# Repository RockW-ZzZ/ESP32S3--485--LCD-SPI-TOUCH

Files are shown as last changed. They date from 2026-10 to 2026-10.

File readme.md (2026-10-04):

# ESP32-S3 双路隔离 RS485 / SPI LCD / 触摸屏

本文是项目文档总入口。目标模组为 **ESP32-S3-WROOM-1U-N16R8**（16 MB Flash、
8 MB Octal PSRAM），固件使用本机 **ESP-IDF 6.1**，项目目录沿用 `fireware`。

## 当前功能与资源

| 功能 | 外设和 GPIO | 当前行为 |
| --- | --- | --- |
| LCD | ST7796S，SPI2；MOSI1 / SCLK5 / DC3 / CS4 / BL6 / RESET10 | 480×320 横屏，RGB565，上电运行 LVGL 8.4 benchmark |
| 触摸 | GT911；SCL7 / SDA8 / INT9，与 LCD 共用 RESET10 | 上电启用，坐标与横屏一致 |
| RS485 第一路 | UART1；TX17 / RX18 / DE21；CN1 3/4 针 | 独立充电器 1 控制，运行设定每 15 秒写入 |
| RS485 第二路 | UART2；TX11 / RX12 / DE14；CN1 1/2 针 | 独立充电器 2 控制，与第一路并行 |
| CN2 隔离逻辑串口 | UART0；TX43 / RX44 | 默认 115200、8N1 |
| KEY2 | GPIO40，低有效 | 长按 2 秒切换触摸，一次按住只切换一次 |
| KEY1 | GPIO41，低有效 | 保留备用，只读状态，按下/松开各 200 ms 稳定滤波 |
| 下载与日志 | USB Serial/JTAG；GPIO19 / GPIO20 | 不占用三个业务 UART |
| 有源蜂鸣器（新增硬件） | HNB09A03 + SS8050；GPIO13；R30 10 kΩ 基极下拉 | 高电平鸣叫、低电平停止；上电关闭，网页开关 |

两路 485 默认分别运行 demo 充电器协议，独立控制两台充电器。启动先请求关机，运行中
每 15 秒写入电压/电流；首次启动预装设定、开关机和保护停机立即执行。网页提供选路、
CC/CP、预设、爬坡、保护、统计、波形、配色、配网和 OTA。通用 Modbus `03/04/06/10`
驱动保留；关闭充电应用后可启用双路只读示例。详见 [充电控制说明](fireware/CHARGER.md)。

蜂鸣器在最新原理图中已改用 GPIO13，GPIO35～37 继续保留给内部 PSRAM。
器件参数、驱动方式及 R28 装配建议见 [硬件说明第 4.4 节](hardware/原理图说明.md)。

## 文档索引

| 文档或资料 | 维护内容 |
| --- | --- |
| [项目进度](项目进度.md) | 当前阶段、已实现功能、验证边界及后续工作；LCD 保留 LVGL benchmark，暂未移植旧屏幕 UI |
| [硬件原理图说明](hardware/原理图说明.md) | 电源与隔离边界、器件/接口、引脚、UART 分配、样机检查 |
| [原理图 PDF](hardware/PCB/SCH_Schematic1_2026-10-04.pdf) | 当前四页电路连接的原始依据 |
| [立创 EDA 工程](hardware/PCB/ProDoc_Board1_2026-10-04.epro2) | 原理图、器件属性与 BOM 装配标记的编辑源 |
| [LCD 引脚及尺寸图](hardware/LCD/3.5寸LCD尺寸和引脚.png) | 屏幕外形、接口位置 |
| [LCD 模组与芯片资料](hardware/LCD/中景园ZJY350S11CTG21电容触摸技术资料-ST7796) | ST7796、GT911、模块原理图和厂家示例；详细文件见硬件说明索引 |
| [固件使用与 API](fireware/README.md) | 编译/烧录、默认行为、驱动调用、配置与验证步骤 |
| [双路充电控制与网页](fireware/CHARGER.md) | 移植范围、网络入口、15 秒写入时序、厂家协议、API、OTA 与验收 |
| [固件依赖清单](fireware/DEPENDENCIES.md) | 项目内依赖、本机工具、独立构建及删除旧参考目录后的验证 |
| [LVGL 移植说明](fireware/components/lvgl/PORTING.md) | LVGL 版本、包含范围、板级适配、字体/图片与配置 |
| [mDNS 来源与校验](fireware/components/mdns/SOURCE_SHA256.json) | 官方 mDNS 1.10.0 固定提交与文件 SHA-256 |
| [mDNS 许可](fireware/components/mdns/LICENSE) | 已内置 mDNS 的 Apache-2.0 许可 |
| [LVGL 原始许可](fireware/components/lvgl/LICENCE.txt) | 第三方源码的 MIT 许可 |
| [LVGL 文件校验表](fireware/components/lvgl/SOURCE_SHA256.json) | 398 个原始文件的 SHA-256 |
| [固件测试](fireware/tests) | 协议、触摸坐标、双路通信、按键/防误触策略及独立性校验脚本 |

## 构建和使用

在 PowerShell 中：

```powershell
Set-Location fireware
.\build.ps1 build
.\build.ps1 menuconfig
# COM5 为示例，替换为实际 USB Serial/JTAG 端口。
.\build.ps1 -IdfArgs @('-p', 'COM5', 'flash', 'monitor')
```

使用已有 SDK 和工具链，不升级；LVGL、mDNS 和网页资源已内置，构建无需联网下载它们。全部编译所需项目文件已放入 `fireware`，
`ref-code` 可由用户删除；本文及构建均不将它作为必需资料目录。硬件资料保留在 `hardware`。
`demo`、`tmp` 中的现有内容不是正式固件的构建输入。

LVGL benchmark 完成后在屏幕和 USB 日志显示结果。GPIO40 只控制触摸输入，关闭触摸不
停止 LCD 刷新或 benchmark。重新打开时，仍按住屏幕的手指需先松开；状态不保存，重启恢复开启。
GPIO41 没有业务动作。实体充电 UI 与 EC11 暂不移植，后续改用 LVGL 触摸 UI。

默认热点 `ChargerCtrl` / `12345678`；访问 `http://192.168.4.1/` 自动跳转到 8899 端口，
默认 PIN `1234`。STA 配网后可通过局域网 IP 或 `charger.local` 访问。
本次新增双 OTA 应用槽，首次从旧固件升级需通过 USB 完整烧录分区表和应用。

## 文档维护规则

1. 电路、位号或接口改变时，同步更新硬件说明、原理图导出文件及该说明中的 SHA-256。
2. GPIO/UART/按键行为改变时，同时更新固件 `board_pins.h`、驱动/配置、固件 README 与本页资源表。
3. 新增第三方源码或资源时，文件与许可放入 `fireware`，更新依赖清单和相应版本/校验记录。
4. 新增正式文档时，在本页索引登记，使用相对链接；不要链接计划删除的旧参考目录。
5. 验证记录区分编译、主机模拟测试与实板测试，不用编译通过代替实机通信或 FPS 结果。

2026-10-05：本轮验证记录见 [充电控制说明](fireware/CHARGER.md#验证与实板验收)。
测试包含原有 19 组驱动测试、新增 14 组充电控制测试和内嵌网页脚本测试。
未检测到串口设备，尚无本轮实板烧录、充电、双路总线或 FPS 测量结果。

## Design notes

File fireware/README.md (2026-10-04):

# ESP32-S3 双路充电控制、横屏驱动与 LVGL benchmark

目标模组：**ESP32-S3-WROOM-1U-N16R8**，16 MB Flash、8 MB Octal PSRAM。
项目目录沿用要求中的 `fireware`。LCD 为 **480×320 横屏**，默认上电运行从
本地内置的 **LVGL 8.4.0 demo benchmark**；底层驱动不依赖 LVGL。
两路 RS485 分别使用 UART1/UART2，CN2 使用 UART0，控制台使用 USB Serial/JTAG。
本工程不再依赖旧 `ref-code` 目录，可删除该目录；完整依赖见 [DEPENDENCIES.md](DEPENDENCIES.md)。
全部文档入口见 [根目录 readme.md](../readme.md)。

## 硬件与参考依据

- 板级引脚：`../hardware/PCB/SCH_Schematic1_2026-10-04.pdf` 第 2～4 页。
- 当前硬件与接口说明：[双路隔离 RS485 原理图说明](../hardware/原理图说明.md)。
- 屏幕：ZJY350S11CTG21，ST7796S，原生 320×480，四线 SPI，RGB565；
  使用厂家 `USE_HORIZONTAL=2` 对应的 `MADCTL=0x28`，逻辑分辨率 480×320。
- LCD 初始化寄存器：屏幕资料 `03-程序源码.zip` 内 STM32F407 SPI 示例 `HARDWARE/LCD/lcd_init.c`。
- GT911 地址、时序和寄存器：屏幕资料内 `GT911 Datasheet_20130319.pdf`；模块 `02-原理图.zip` 确认 LCD RESET 与 CTP_RST 共用 `RES`。
- ST7796 初始化表、UART 半双工控制与 Modbus 协议实现在 `components/board_drivers`。
  当前屏幕 gamma/VCOM 采用当前厂家示例，所需数据已编入源码。
- LVGL 源码与 benchmark：`components/lvgl`，版本 8.4.0。
  原样保留核心、benchmark 资源和 MIT 许可证，详情见 [PORTING.md](components/lvgl/PORTING.md)。
- 参考工程是旧板：FT6336、TCA9554、AXP2101、GPIO0 按键和 4G 未引入。
  本板通过独立 `board_lvgl` 组件连接 ST7796 / GT911。

| 模块 | 外设 | GPIO / 配置 |
| --- | --- | --- |
| LCD MOSI / SCLK | SPI2 | GPIO1 / GPIO5，默认 20 MHz，SPI mode 0 |
| LCD DC / CS | GPIO | GPIO3 / GPIO4 |
| LCD 背光 | LEDC timer0/channel0 | GPIO6，高电平亮，5 kHz，10 bit |
| LCD + GT911 复位 | 共用 RES | GPIO10，低有效 |
| GT911 SCL / SDA | I2C0 | GPIO7 / GPIO8，100 kHz |
| GT911 INT | GPIO | GPIO9；复位时选地址，运行时输入 |
| 隔离 RS485 第一路，CN1 3/4 | UART1 + U5 ISO3082 | TX17 / RX18 / DE 与 /RE = GPIO21 |
| 隔离 RS485 第二路，CN1 1/2 | UART2 + U7 ISO3082 | TX11 / RX12 / DE 与 /RE = GPIO14 |
| KEY1，保留输入 | GPIO41，低有效 | 双边沿 200 ms 稳定滤波，仅查询状态 |
| KEY2，触摸开关 | GPIO40，低有效 | 30 ms 消抖，稳定按下后长按 2 秒切换触摸 |
| 隔离串口 CN2 | UART0 + CA-IS3722HS | TX43 / RX44，默认 115200，8N1 |
| USB 日志与下载 | USB Serial/JTAG | GPIO19 / GPIO20 |

GPIO2 对应 H1 第 12 针预留 MISO；当前屏幕 11 针接口未接 SDO，因此 SPI 设置 `miso_io_num=-1`。
GPIO35～37 不作外设 GPIO 使用，保留给 N16R8 模组内部 Octal PSRAM。
最新原理图新增的 HNB09A03 有源蜂鸣器已接 GPIO13，并设 R30 10 kΩ 基极下拉。
固件已加入默认关闭的 GPIO13 蜂鸣器开关（高电平响、低电平停），网页可控制，详见 [硬件说明第 4.4 节](../hardware/原理图说明.md)。
KEY1/KEY2 不包含 BOOT(GPIO0) 与硬件复位键。

## 本机编译

使用已有安装，不下载或切换 ESP-IDF：

- ESP-IDF：`C:\esp\v6.1\esp-idf`，版本 `v6.1`。
- Xtensa GCC：`C:\Espressif\tools\xtensa-esp-elf\esp-15.2.0_20251204`，GCC 15.2.0。
- Python：`C:\Espressif\tools\python\v6.1\venv\Scripts\python.exe`。
- 安装器环境文件：`C:\Espressif\tools\Microsoft.v6.1.PowerShell_profile.ps1`。

在 `fireware` 内运行：

```powershell
.\build.ps1 build
.\build.ps1 menuconfig
.\build.ps1 size
# COM5 仅为示例，替换为本机实际 USB Serial/JTAG 端口。
.\build.ps1 -IdfArgs @('-p', 'COM5', 'flash', 'monitor')
```

本机 ESP-IDF 6.1 的编译参数文件生成过程会破坏中文路径。`build.ps1` 与
`tools/idf_short_path.py` 保留本项目的 NTFS 英文短路径，指向同一份源码和 `build`
目录；不复制源码、不映射盘符、不修改 ESP-IDF 安装或全局 Git 配置。
因此在当前中文目录下使用此脚本，而不是直接运行 `idf.py`。
若拷贝到禁用 8.3 短文件名的磁盘，请使用英文项目路径。
安装位置改变时可用 `-IdfProfile` 指向对应版本的本机安装器环境文件。

默认 CPU 240 MHz、性能优化编译，Flash DIO 40 MHz，PSRAM Octal 80 MHz，启动时初始化与内存测试。
使用 `partitions.csv`：NVS 20 KiB、OTA 元数据 8 KiB、两个各 4 MiB 的 OTA 应用槽，
其余 Flash 未分配。从旧单应用固件迁移时必须通过 USB 烧录新分区表，不能仅 app-flash。
需要完整烧录时使用 `flash`，它会按生成的分区表烧录 bootloader、分区表和 app。

## 启动示例

`main/app_main.c` 先初始化 GPIO13 为关闭和 NVS，再初始化 LCD、触摸、按键、CN2 串口、
两路 485、充电业务及网络；充电业务详见 [CHARGER.md](CHARGER.md)。

- LCD 清黑后背光 80%，独立 GUI 任务自动运行一次 LVGL benchmark，全速模式。
  完成后屏幕显示可触摸滚动的结果表，USB 日志输出 `Weighted FPS`、`Opa. speed`
  及各场景 FPS。复位可重新测试；没有预填或模拟 FPS 数值。
- GT911 作为 LVGL pointer 输入。benchmark 运行时由 LVGL 独占触摸帧读取，
  主循环不再读取同一就绪寄存器，避免漏报或错误释放。
- 如需纯驱动测试，在 `Board basic drivers` 关闭 `Run LVGL 8 benchmark at boot`，
  再开启 RGB 色条；此时触摸坐标与释放事件恢复输出到 USB 日志。
- 上电默认开启触摸；GPIO40 长按 2 秒切换开启/关闭，每次持续按住只切换一次，
  必须松开后再次长按才能再次切换。状态不保存到 Flash，重启恢复开启。
- GPIO41 保留备用；按下和松开均需稳定 200 ms，只读取状态并记录变化，无业务动作、无长按事件。
- CN2 串口收到数据时以十六进制输出到 USB；回显默认关闭，可在 menuconfig 开启。
- 两路 485 上电均初始化，默认各为 9600、8N1；可分别配置波特率、校验、停止位。
  两路均提供 Modbus RTU 主站 API，独立锁和 RX 队列；一路等待响应或超时不占用另一路。
- 默认启用 `BOARD_CHARGER_APP`，两路各控制一台 demo 协议充电器，默认地址 0。
  上电请求关机并读取状态；网页人工启动后运行，设定每 15 秒写入，开关/保护立即执行。
  网络热点、网页、参数与 OTA 见 [充电控制说明](CHARGER.md)。
- 要使用通用只读示例，在 `Board basic drivers` 先关闭充电应用，再启用
  `Enable two concurrent READ-ONLY Modbus demo tasks`；两个功能不会同时占用业务总线。
  示例各自默认地址 1、功能码 03、寄存器 0，读取 2 个寄存器，超时 2 秒，事务后等 2 秒。
- 单个外设初始化失败会记录错误，其余模块仍继续初始化；PSRAM 启动检测由 IDF 自身处理。

应用日志与 bootloader 控制台走 USB。ESP32-S3 ROM 在应用运行之前仍可能从
默认 UART0/GPIO43 输出启动字节；未修改 eFuse。CN2 外部设备应能忽略上电杂字节。
三个 UART 均用于业务接口，不能再将应用控制台切换到 UART；串口驱动有编译期检查。

## LVGL 移植设置

- 本地组件 `components/lvgl` 使用原始 Kconfig；配置来源是 `sdkconfig`，
  初始值在 `sdkconfig.defaults`。不需要联网下载组件，也不需要另写 `lv_conf.h`。
- RGB565，`LV_COLOR_16_SWAP=n`：字节序仅在 LCD 驱动中转换一次。
- 单个 PSRAM 绘图缓冲默认 480×40 像素（38,400 字节）；可调 10～80 行。
  LCD 使用内部 DMA 缓冲分块发送，等待 SPI 完成后才调用 `lv_disp_flush_ready()`。
  这是同步 SPI 移植，benchmark 包含该传输开销。
- `esp_timer` 每 5 ms 更新 tick；GUI 任务栈 8 KB、优先级 4，双核时运行在核 1。
  `lv_timer_handler()` 循环至少让出 1 tick，触摸读取周期 20 ms。
- 开启压缩字体、复杂绘制及 benchmark 所需控件；LVGL malloc/free 使用 IDF 堆，
  由已启用的 PSRAM malloc 策略分配大块内存。
- 默认 SPI 保持 20 MHz。可在 menuconfig 调到 40 MHz，但实际稳定性需上板检查。
  比较 FPS 时应记录 CPU/SPI 频率、缓冲大小和优化等级，测试期间避免其他串口负载及触摸操作。
- LVGL 所有对象操作应在 GUI 任务中执行。当前没有对外提供跨任务 LVGL 锁或对象接口。
  同时从其他任务调用 LCD 绘图接口会覆盖 benchmark 画面，应在关闭 benchmark 后做色条测试。
- 为减少工程体积，仅内置核心和 benchmark；其他 demo/examples 未包含，若在 LVGL 菜单
  勾选会明确报配置错误。以后如需扩展，应引入匹配版本的完整资源和许可，再更新依赖表。

## 驱动接口

所有 `*_init()` 在启动时由一个任务顺序调用；运行期 API 从任务调用，不可在 ISR 调用。
驱动按设备整个运行周期持有资源，不提供运行中卸载 API。LCD/触摸初始化可重复调用；
串口和每一路 485 重复初始化返回 `ESP_ERR_INVALID_STATE`。现有 `app_main()` 已初始化
这些设备；下列初始化片段用于编写独立应用时参考，不要在已运行的应用中重复初始化。

### 蜂鸣器

`buzzer_init()` 在启动最早阶段将 GPIO13 设为 LOW；`buzzer_set(true/false)` 开关声音，
`buzzer_is_on()` 查询状态。状态不保存，重启关闭。仅有源蜂鸣器开关，不使用 PWM。

### LCD

```c
#include "lcd_st7796.h"
ESP_ERROR_CHECK(lcd_init());
ESP_ERROR_CHECK(lcd_fill(0x0000));
ESP_ERROR_CHECK(lcd_fill_rect(20, 30, 100, 60, 0xF800));
ESP_ERROR_CHECK(lcd_set_backlight(80));
// pixels 至少包含 width * height 个 uint16_t RGB565 像素。
ESP_ERROR_CHECK(lcd_draw_rgb565(x, y, width, height, pixels, pixel_count));
```

横屏左上为 `(0,0)`，有效范围 `x=0..479`、`y=0..319`，矩形参数为宽高。
RGB565 采用主机 `uint16_t` 值，红色 `0xF800`；驱动转换为高字节先发送。
同步 SPI DMA 传输，内部 7,680 字节缓冲；函数返回后调用方可立即复用像素数据，
不要求调用方缓冲在 DMA 内存中。矩形越界返回参数错误，不隐式裁剪。
并发绘图与背光调用由互斥锁串行化，不提供全屏帧缓存或撕裂同步。

### GT911

```c
#include "touch_gt911.h"
ESP_ERROR_CHECK(touch_init());
ESP_ERROR_CHECK(touch_set_enabled(false)); // 屏蔽触摸，不影响 LCD 和 benchmark。
ESP_ERROR_CHECK(touch_set_enabled(true));  // 恢复；仍按住的手指先松开再触摸。
bool enabled = touch_is_enabled();
touch_frame_t frame;
esp_err_t err = touch_read(&frame);
if (err == ESP_OK && frame.updated) {
    // count=0 表示释放；count=1..5，points[] 包含 id/x/y/size。
}
```

`updated=false` 表示没有新帧，不能当成松手。读取所有点后才清 `0x814E` 就绪位；
I2C 读取失败返回错误，不伪造触点。先按芯片报告的分辨率归一到原生 320×480，
再应用横屏变换 `(x,y) → (y,319-x)`，输出范围与 LCD 的 480×320 一致。
原生左上角映射为横屏左下角，原生右上角映射为横屏左上角。
保留厂家传感器配置，不下发未经确认的 GT911 配置表；menuconfig 的交换/镜像
用于校准原生传感器方向，在固定横屏旋转之前应用，默认均关闭。
读取接口只能有一个消费者；LVGL 活动时应用不要另外调用 `touch_read()`。
`touch_set_enabled()` 和 `touch_is_enabled()` 可由其他任务调用，与 I²C 读取共用驱动锁。
关闭后仍读取并确认 GT911 数据，输出释放状态；重新开启前丢弃挂起帧，屏蔽尚未松开的
触点，避免重放旧触摸。切换模式时 `frame.input_reset=true`，自定义 UI 应取消旧手势。
LVGL 适配在 GUI 任务中调用 `lv_indev_reset()`，避免把关触摸动作解释为一次点击。
轮询寄存器，INT 不用于中断唤醒，避免依赖厂商配置中的中断极性。
首次显示/触摸初始化统一完成共用 GPIO10 复位与地址选择，优先 7 位地址 `0x5D`，
探测失败再尝试 `0x14`。之后 LCD 仅做 ST7796 软件复位，避免重置已启动的触摸。

### GPIO 按键

```c
#include "buttons.h"
ESP_ERROR_CHECK(buttons_init());
button_event_t event;
if (buttons_get_event(&event, pdMS_TO_TICKS(100))) {
    // event.id: BUTTON_KEY2（GPIO40）；GPIO41 不产生事件。
    // event.type: BUTTON_PRESSED / BUTTON_RELEASED / BUTTON_LONG_PRESS
}
bool pressed = buttons_is_pressed(BUTTON_KEY1);
```

驱动每 5 ms 扫描。GPIO40 的按下/释放稳定 30 ms 后生效，从有效按下起计时 2000 ms
产生一次 LONG_PRESS；保持按住不会重复触发，松手仍有 RELEASED。应用消费这个长按
事件切换触摸。事件队列最多 16 项，单消费者；满时丢最旧事件并输出告警。
GPIO41 按下/释放均稳定 200 ms 后更新 `buttons_is_pressed(BUTTON_KEY1)`，不加入事件队列。

### 隔离串口

```c
#include "serial_port.h"
ESP_ERROR_CHECK(serial_port_init(115200, UART_PARITY_DISABLE, UART_STOP_BITS_1));
uint8_t rx[128];
int n = serial_port_read(rx, sizeof(rx), pdMS_TO_TICKS(100));
const uint8_t tx[] = {0x01, 0x02, 0x03};
ESP_ERROR_CHECK(serial_port_write(tx, sizeof(tx)));
```

支持 1200～115200 baud、无/奇/偶校验、1/2 停止位，8 数据位。RX 环形缓冲 2048 字节；
`read()` 为单消费者，返回实际长度、0 超时或 -1 错误。`write()` 对多任务串行化，
阻塞到发送完成，单次上限 4096 字节。应用需及时读取，持续灌入而不读取会丢数据。
CN2 隔离侧 VDDB/GNDB 需要按原理图接外部电源/参考地，不能误当 RS232 或 RS485 电平。

### 双路 Modbus RTU 主站 / 隔离 RS485

```c
#include "modbus_rtu.h"
ESP_ERROR_CHECK(rs485_init(RS485_PORT_1, 9600, UART_PARITY_DISABLE, UART_STOP_BITS_1));
ESP_ERROR_CHECK(rs485_init(RS485_PORT_2, 19200, UART_PARITY_EVEN, UART_STOP_BITS_1));
uint16_t regs[2];
uint8_t exception;
esp_err_t err = modbus_read_registers(RS485_PORT_1, 1, 0x03, 0, 2, regs, 2000, &exception);
// 在另一个任务中，以自己的 regs/exception 调用 RS485_PORT_2，即可并行通信。
// 0x04 输入寄存器同样使用 modbus_read_registers。
// 下列操作会写外部设备，按其寄存器手册明确选择地址和值后再调用：
// err = modbus_write_single(RS485_PORT_2, 1, 0x0010, 123, 2000, &exception);
// uint16_t values[] = {123, 456};
// err = modbus_write_multiple(RS485_PORT_2, 1, 0x0010, 2, values, 2000, &exception);
```

- 功能码 `03/04` 读取 1～125 个寄存器，`06` 写单寄存器，`10` 写 1～123 个寄存器。
- 从站地址 1～247，不支持地址 0 广播。寄存器采用零基址，不直接填 `40001`。
- API 第一个参数明确选择 `RS485_PORT_1` / `RS485_PORT_2`；旧版无通道参数的调用需更新。
  两路支持相同的 `03/04/06/10` 功能码，各自维护 UART、波特率、帧间隔、事件队列和事务锁。
- 同一路的请求与应答整体由锁保护，多个调用者排队；不同路的两个任务可同时通信。
  一路超时、CRC 错误或初始化失败不会清除另一路接收队列。完整两任务示例见 `main/app_main.c`。
- UART1 的 RTS 自动控制 GPIO21，UART2 的 RTS 自动控制 GPIO14：高发送、低接收，
  等待最后一个停止位完成后接收。两路初始化均先保持方向低电平。
- 发送前清理残留数据并等待总线空闲；超过 19200 baud 按 1.75 ms 基准设置帧间隔，
  低速按 3.5 字符计算，UART 空闲中断阈值向上取整到整字符。接收以空闲事件结束，
  FIFO 满事件仅作为分片；检查 CRC、地址、功能码、字节数、长度、写回显与异常响应。
- UART 奇偶/帧错误及 RX 溢出使事务失败。响应超时覆盖完整响应帧；另有锁等待和
  总线空闲等待，所以函数总耗时可能大于 `timeout_ms`。不自动重发写请求。
- `ESP_ERR_MODBUS_EXCEPTION` 时读取 `exception`；CRC、超时、帧错误分别返回
  `ESP_ERR_INVALID_CRC`、`ESP_ERR_TIMEOUT`、`ESP_ERR_INVALID_RESPONSE` 等。失败不覆盖读寄存器输出。
- 每条物理总线是基本单主站实现，不含从站寄存器服务。未做严格的 1.5 字符帧内间隔检测，
  也不能识别“前一个已超时的相同请求”的迟到应答；应用应按设备最大响应时间设超时，
  避免立即重试。不用于宣称 Modbus 时序一致性认证。

串口格式必须与各自从站匹配。默认是常见传感器的 8N1；若按标准无校验格式使用，
选择 8N2，或按设备配置使用 8E1。`BOARD_RS4851_*` / `BOARD_RS4852_*` 是独立配置项；
旧单路配置通过 `main/sdkconfig.rename` 迁移为第一路配置。
原理图两路终端为 R15/R22，偏置为 R12/R18 与 R19/R25。两路同时发送的场景是两条独立
总线；若 CN1 仅用于兼容同一设备的两种引脚定义，应只向实际连接的通道发请求。
完整 RS485 收发需 VIN 为两路总线侧 A5V 供电，USB 单供电不足以验证隔离侧通信。

## 验证与上板检查

主机协议测试直接编译 `modbus_codec.c` 为测试 DLL，再从 Python 执行，不复制实现：

```powershell
& 'C:\Espressif\tools\python\v6.1\venv\Scripts\python.exe' tests\test_modbus_codec.py
& 'C:\Espressif\tools\python\v6.1\venv\Scripts\python.exe' tests\test_touch_mapping.py
& 'C:\Espressif\tools\python\v6.1\venv\Scripts\python.exe' tests\test_runtime.py
& 'C:\Espressif\tools\python\v6.1\venv\Scripts\python.exe' tests\check_dependencies.py
```

测试用本机已安装 Visual Studio 18 MSVC 14.51 和 Windows SDK 10.0.26100；
这是主机测试编译器，固件仍完全使用本机 ESP-IDF Xtensa GCC。
路径不同可传 `--msvc-bin`、`--sdk-include`。覆盖固定 CRC/报文向量、03/04/06/10、
异常帧、坏 CRC、错误地址/功能码/回显、短帧、125/123 寄存器边界、地址溢出、
缓冲区边界和 500 组固定随机种子的有效报文。

横屏坐标测试直接编译驱动使用的 `touch_mapping.h`，覆盖四角、153,600 个原生像素
的一一映射、不同传感器分辨率、校准选项、边界与无效输入。

运行期测试编译实际 `rs485.c`、`modbus_rtu.c`、`serial_port.c`，仅将 IDF I/O 替换为主机
锁和模拟 UART 队列。覆盖 UART 分配、失败重试、不同波特率、双路同地址并发、单路事务
串行化、一路超时不阻塞另一路、两路写入和异常响应，以及按键阈值和触摸屏蔽策略。
这些测试验证软件资源与状态隔离，不证明实物 UART 时序或电气性能。

当前验证结果（2026-10-05）：主工程与仅含固件输入的独立副本均用本机 ESP-IDF 6.1
构建通过。应用约 1.26 MiB，每个 4 MiB OTA 槽剩余约 68%。原有 7 组协议、4 组坐标、
8 组运行期测试及新增 14 组充电控制测试通过，内嵌网页脚本检查通过。
398 个 LVGL 文件和 40 个 mDNS 文件均由本地 SHA-256 校验。LVGL 文本校验仅容许
Git 的 LF/CRLF 换行转换；mDNS 和二进制资源按原始字节校验。
独立副本无旧 build/sdkconfig、demo 或硬件资料，充电控制/网络/网页/OTA 均可从零构建。
可按 [依赖说明](DEPENDENCIES.md) 复现；新增功能与实板边界见 [CHARGER.md](CHARGER.md)。
色条、串口回显、Modbus 示例、奇/偶校验、触摸坐标变换以及关闭 GUI 的可选分支已用同一套
Xtensa GCC 单独编译检查，未改变默认固件配置；复现命令为：

```powershell
& 'C:\Espressif\tools\python\v6.1\venv\Scripts\python.exe' tests\check_optional_build.py
```

产物：`build/esp32s3_basic_drivers.bin`、`build/bootloader/bootloader.bin`、
`build/partition_table/partition-table.bin`。整板首次烧录使用 `build.ps1 ... flash`，
不要把仅应用镜像直接烧到地址 0。

编译和主机测试不能替代实板检查；本机未检测到串口设备，尚未烧录，暂无实机 FPS。
连接开发板后执行上面的 `flash monitor` 命令，固件会自动开始 benchmark。建议按顺序确认：

1. USB 启动日志中的 PSRAM 为 8388608 bytes；显示/触摸初始化成功。
2. 屏幕以 480×320 横屏运行 benchmark，完成后屏幕及 USB 输出结果；日志无 flush 错误。
3. 用触摸滚动结果表验证方向与释放；需要完整五点/四角测试时关闭 benchmark，
   开启色条模式查看原始驱动日志，同时核对红绿蓝、横屏方向与背光。
4. GPIO40 短按不切换，长按 2 秒切换一次，保持按住不重复；触摸关闭时 benchmark
   继续运行。关闭前和开启时保持手指按屏，确认无旧点击，松手后恢复。重启默认开启。
   GPIO41 小于 200 ms 的跳变被滤除，稳定按下/松开可读且不触发业务动作。
5. CN2 隔离侧正确供电，通过串口适配器测试收发；回显需显式开启。
6. 默认充电应用按 [充电验收步骤](CHARGER.md#验证与实板验收) 验证。若测试通用 Modbus，
   先关闭充电应用，两路分别连接已知 Modbus 从站，核对每路配置后开启双任务只读示例；断开一路时另一路
   仍应持续收到正确应答。再按设备手册测试允许写的寄存器，检查超时、错误波特率、
   异常码，以及 GPIO21/GPIO14 在各自收发结束后的电平。

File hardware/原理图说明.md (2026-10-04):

# ESP32-S3 双路隔离 RS485 与 LCD 触摸屏原理图说明

文档版本：V1.2（增加 GPIO13 有源蜂鸣器与基极下拉）  
编写日期：2026-10-04  
适用硬件：Board1 / Schematic1，2026-10-04 23:52 导出版，双路 ISO3082 与有源蜂鸣器方案。

本文说明当前电路的供电、隔离、信号连接、接口定义及固件配合要求，供硬件制作、固件开发和样机调试使用。器件位号与参数以当前工程为准；文中标为“建议”或“待验证”的内容尚未落实为硬件修改或实测结论。

项目文档总入口：[根目录 readme.md](../readme.md)。本版同步新增蜂鸣器电路：控制已改为 GPIO13，R30 基极下拉已加入；固件已加入 GPIO13 开关控制，上电关闭，网页可开/关。

## 1. 设计依据与使用条件

| 项目 | 本版采用的条件 |
| --- | --- |
| 外部供电 | CN3 输入直流 12～15 V |
| 主控 | U4：ESP32-S3-WROOM-1U；工程器件名称未写明 Flash/PSRAM 容量后缀 |
| RS485 | U5、U7 两路 ISO3082DWR，各有独立 TX、RX 和方向控制 GPIO |
| 引脚兼容方式 | CN1 的 1/2 与 3/4 两组引脚兼容同一外部设备的不同定义，由固件选择通信通道；未选引脚不带外部电源 |
| 独立串口 | U6：CA-IS3722HS，隔离逻辑电平 UART，通过 CN2 连接外部设备 |
| LCD 模块 | 中景园 ZJY350S11CTG21，ST7796S 显示驱动、GT911 电容触摸，实际接口 11 针 |
| LCD 电源与功耗 | 3.3 V；整模块功率按已确认的 0.2 W 估算，约 61 mA |
| LCD 调试预留 | H1 使用 12 针，额外第 12 针为 GPIO2/MISO 预留 |
| 蜂鸣器 | BUZZER1：HNB09A03 有源电磁式，3V3 供电，GPIO13 经 Q1 低侧驱动，R30 10 kΩ 基极下拉 |
| USB 供电 | VBUS 经 D2 接入隔离电源输出侧的 `5V`，用于临时调试 |
| 本版方案 | 已取消模拟开关；GPIO14 用于第二路 RS485 方向控制 |

主要依据：[当前原理图 PDF](PCB/SCH_Schematic1_2026-10-04.pdf)、[立创 EDA 专业版工程](PCB/ProDoc_Board1_2026-10-04.epro2)，以及 [LCD 尺寸与引脚图](LCD/3.5寸LCD尺寸和引脚.png)。PDF 共四页：第 1 页 POWER、第 2 页 ESP32S3、第 3 页隔离通信、第 4 页 LCD。

当前工程已包含 PCB 器件与网络数据。本版仅核对原理图及器件属性，未对 PCB 布局布线进行完整评审；本文不代表已完成 PCB 间距、走线、散热或 EMC 验证。

## 2. 系统结构与隔离边界

### 2.1 电源路径

```mermaid
flowchart LR
    VIN["CN3：12～15 V"] --> INPUT["D1 / L1 / D3：输入保护与滤波"]
    INPUT --> BUCK["U1：XL1509，降压"]
    BUCK --> A5V["A5V / AGND"]
    A5V --> BUS["U5 / U7 的 RS485 总线侧"]
    A5V --> ISO["U2：B0505S-2WR3，隔离变换"]
    ISO --> V5["5V / GND"]
    USB["USB VBUS"] --> D2["D2：调试供电二极管"]
    D2 --> V5
    V5 --> LDO["U3：BL8072，3.3 V LDO"]
    LDO --> V33["3V3 / GND"]
    V33 --> MCU["ESP32-S3、LCD、触摸及隔离器逻辑侧"]
    V33 --> BUZZER["有源蜂鸣器及 Q1 驱动支路"]
```

此图表示供电关系，U2 输入侧和输出侧之间包含电气隔离。

### 2.2 电源和地的含义

| 网络 | 所属区域 | 主要连接 |
| --- | --- | --- |
| `VIN+`、`VIN-` | 外部电源输入 | CN3，经保护与滤波后进入降压电路 |
| `A5V`、`AGND` | 外部电源及通信侧 | U1 输出、U2 输入、U5/U7 总线侧；U6 的 GNDB 也接 AGND |
| `5V`、`GND` | 隔离后的主控侧 | U2 输出、D2 输出、U3 输入 |
| `3V3`、`GND` | 主控侧低压电源 | ESP32-S3、LCD、触摸、蜂鸣器、U5/U7 逻辑侧和 U6 的 VDDA/GNDA |
| U6 `VDDB`、`AGND` | CN2 外部串口侧 | VDDB 由 CN2 第 1 针输入，未在板上连接 A5V |

本工程的 `AGND` 表示外部电源和通信侧参考地。主控 `GND` 与 `AGND` 通过 U2、U5、U6、U7 各自的隔离结构分开，PCB 布局布线应保持这一边界。

两路 RS485 共用 A5V 和 AGND，CN2 外部串口侧也共用 AGND。因此它们与主控侧隔离，**各通信接口之间没有独立的地隔离**。USB 接入后，主控 GND 与 USB 主机地相连。

## 3. 电源电路（原理图第 1 页）

### 3.1 输入保护与 5 V 降压

CN3 第 1 针接 VIN+，第 2 针接 VIN-，输入范围按 12～15 V 使用。VIN- 经过 L1 的一组绕组进入 AGND。

| 器件 | 当前型号或数值 | 作用 |
| --- | --- | --- |
| D1 | SMF18CA，双向 TVS | 跨接 VIN+ 与 VIN-，用于抑制输入瞬态过压 |
| L1 | SMW3225S102HTE | 双线共模滤波，输入正负两根线分别通过一组绕组 |
| D3 | DSK24 | 串联在正电源路径，提供反接阻断并产生一定正向压降 |
| C1 | 10 µF / 50 V | 降压电路输入储能与滤波 |
| U1 | XL1509-5.0E1 | 固定 5 V 降压芯片，输出网络名为 A5V |
| D4 | DSK24 | 降压电路续流二极管 |
| L2 | 47 µH，FNR5040S470MT | 降压输出储能电感 |
| C7 | 220 µF / 10 V | A5V 输出滤波 |

U1 的反馈脚检测 A5V，ON/OFF 脚接 AGND，使降压电路随 VIN 上电工作。整机可用电流还受 L1、L2、二极管、温升和后级隔离电源限制，不能直接用 U1 的芯片额定电流代表整板供电能力。

### 3.2 隔离变换与 3.3 V 稳压

U2 为易川 YLPTEC 的 B0505S-2WR3，工程物料号 C5369473。输入为 A5V/AGND，输出为 5V/GND；该器件是标称 5 V、400 mA、2 W 的隔离非稳压模块，输出电压会随负载变化。[工程关联的易川器件手册](https://atta.szlcsc.com/upload/public/pdf/source/20230427/82014D73CB8555D1D44C1887F1D9A3CE.pdf)

U3 为 BL8072CLTR33，将 5V 转为 3V3。C2、C3 各 10 µF 位于 5V 侧，C4、C5 各 10 µF 和 C6 100 nF 位于 3V3 侧。U3 属于线性稳压器，电压差对应的功率主要转换为热量。

按已确认的 LCD 整模块功率估算：

```text
LCD 电流 ≈ 0.2 W ÷ 3.3 V ≈ 61 mA
U3 耗散 ≈ (5.0 V − 3.3 V) × 3V3 总负载电流
例如 3V3 总负载为 300 mA 时，U3 耗散约 0.51 W
```

U2 的 400 mA 输出经过 LDO 后，不会按 2 W ÷ 3.3 V 转换成更大的输出电流。忽略稳压器自身电流时，扣除 LCD 后约剩 339 mA。新增蜂鸣器若按器件规格中的 30 mA，加上当前 R28 支路约 7 mA 和 Q1 基极约 2.5 mA 估算，鸣叫时还需预留约 40 mA，剩余约 300 mA 给主控及其他主控侧负载。蜂鸣器在实际供电电压下的电流仍需实测；上述数值是预算，不是瞬态供电保证，应验证开机、鸣叫、无线发射及显示刷新时的压降和温升。

### 3.3 USB 临时供电

USB VBUS 经 D2 接到 U2 输出所在的 5V 网络，再通过 U3 为主控侧供电。这是本版已确认的临时调试接法。

| 供电方式 | 可供电部分 | 使用说明 |
| --- | --- | --- |
| 仅 VIN | A5V、隔离后的 5V 和 3V3 | 可进行整板功能调试；CN2 的 VDDB 仍需外部供电 |
| 仅 USB | 5V、3V3 及主控侧负载 | 用于下载、日志、LCD、触摸、按键调试；USB 经 D2 后的电压会低于 VBUS |
| VIN 与 USB 同时连接 | 两种电源同时接入当前电路 | 属于调试接线状态，本文未将其视为已经实测验证的自动电源切换功能 |

**仅 USB 供电不产生 A5V，也不向 CN2 的 VDDB 供电。** U5/U7 的总线侧缺少工作电源，不能据此测试完整 RS485 收发。D2 的单向性也不等同于对 U2 输出端增加了独立的反向隔离或电源管理。

## 4. ESP32-S3 最小系统与 USB（原理图第 2 页）

### 4.1 主控、复位与启动

U4 使用 ESP32-S3-WROOM-1U 模组，3V3 供电，C11、C12 各为 100 nF。现有固件以 N16R8（16 MB Flash、8 MB Octal PSRAM）为目标，但工程器件名只有 WROOM-1U；采购和贴装时应核对完整模组后缀。

| 电路 | 当前连接 | 行为 |
| --- | --- | --- |
| BOOT | GPIO0，R8 10 kΩ 上拉，C10 100 nF，BOOT1 接地 | 正常保持高电平；下载操作时配合复位拉低 |
| EN / RESET | R9 10 kΩ 上拉，C13 100 nF，RST1 接地 | 按下 RST1 将 EN 拉低，释放后重新启动 |
| KEY1 | GPIO41，R10 10 kΩ 上拉，C14 100 nF | 按下为低电平；固件仅查询状态，双边沿 200 ms 稳定滤波，保留备用 |
| KEY2 | GPIO40，R11 10 kΩ 上拉，C15 100 nF | 按下为低电平；固件长按 2 秒切换触摸开关，一次按住只切换一次，上电触摸默认开启 |

SW1、SW2、SW3 分别为复位、KEY1、KEY2 的并联备用按键封装，当前不加入 BOM。GPIO0、GPIO3、GPIO45、GPIO46 涉及启动配置，其中 GPIO3 已用于 LCD-DC，应保持复位期间的外部电平符合模组启动要求。[ESP32-S3 模组手册](https://www.espressif.com/sites/default/files/documentation/esp32-s3-wroom-1_wroom-1u_datasheet_en.pdf)

### 4.2 32.768 kHz 晶振

GPIO15、GPIO16 连接 X1（32.768 kHz），R2、R3 为 0 Ω，C8、C9 各为 12 pF。R1 为跨接晶振的 1 MΩ 预留电阻，当前不加入 BOM。

工程中 X1 的标称负载电容为 12.5 pF。两只 12 pF 电容对晶振形成的等效负载还包含串联等效和寄生电容，不能直接视为 12.5 pF。若启用外部低速晶振，应在样机上验证起振和频率误差；未使用时，固件不应仅因原理图存在 X1 就假定外部时钟可用。

### 4.3 USB-C

| 信号 | 当前连接 |
| --- | --- |
| D− | USB_N，经 R4 0 Ω 接 GPIO19 |
| D+ | USB_P，经 R6 0 Ω 接 GPIO20 |
| CC1、CC2 | 各通过一只 5.1 kΩ 电阻（R5、R7）下拉到 GND |
| VBUS | 经 D2 接主控侧 5V 调试电源 |
| USB 地及外壳连接 | 接主控 GND |

连接器正反插对应的 D+ 接点共网，D− 接点共网。当前电路使用 ESP32-S3 原生 USB，可用于 USB Serial/JTAG 下载和日志。R4、R6 的实际装配值是 0 Ω；固件及制作资料应保留这一事实。

### 4.4 有源蜂鸣器：GPIO13 控制

BUZZER1 的工程型号为华能 HNB09A03（C96102），有源电磁式，内含振荡驱动电路。额定电压 3 V，工程属性列出的工作电压为 1.5～4.5 V，工作电流按 30 mA 量级考虑，3V3 经 Q1 驱动适合该电压范围。图上“3kHz”是器件的声音频率标注，不是 MCU 必须提供的 PWM 频率；新旧厂家资料的频率标注存在差异，实际音调以采购版本为准。[华能 HNB09A03 厂家规格书](https://xonstorage.z8.web.core.windows.net/pdf/huaneng_hnb09a03_apr22_xonlink.pdf)

| 器件/网络 | 当前工程参数 | 连接与作用 |
| --- | --- | --- |
| BUZZER1 | HNB09A03，有源电磁式，图中标注 3 kHz | 1 脚正极接 3V3，2 脚负极接 Q1 集电极 |
| Q1 | SS8050，SOT-23 | NPN 低侧开关；工程符号 1 脚 B、2 脚 E、3 脚 C，发射极接 GND |
| R29 | 1 kΩ，1%，0.1 W | GPIO → Q1 基极的串联限流电阻 |
| R30 | 10 kΩ，1%，0.1 W | Q1 基极到发射极/GND 的下拉，建立默认关断状态 |
| R28 | 470 Ω，5%，0.1 W | 跨接蜂鸣器两端，连接 3V3 与 Q1 集电极 |
| D7 | DSK24 | 阴极接 3V3，阳极接 Q1 集电极，提供关断瞬态钳位路径 |
| C26 | 100 nF | 3V3 对 GND 的局部去耦 |
| IO13 | GPIO13 / 模组第 21 脚 | 当前蜂鸣器控制网络，经 R29 接 Q1 基极 |

最新原理图已将控制连接改为 **GPIO13**，U4 与 R29 两端的 IO13 网络一致，原 GPIO37 外接负载已移除。N16R8 的 GPIO35、GPIO36、GPIO37 连接模组内部 Octal PSRAM，应继续保留，不能分配给其他外设。[乐鑫模组手册，引脚定义注 b](https://www.espressif.com/sites/default/files/documentation/esp32-s3-wroom-1_wroom-1u_datasheet_en.pdf)

驱动逻辑如下：

| GPIO 输出 | Q1 状态 | 蜂鸣器行为 |
| --- | --- | --- |
| 低电平 | 截止 | 停止发声 |
| 高电平 | 导通 | 接通直流电源，持续发声 |
| 定时高/低切换 | 定时通断 | 形成短响、长响及间歇提示 |

有源蜂鸣器的提示节奏可用普通 GPIO 和软件定时实现，无需占用 LCD 背光使用的 LEDC timer0/channel0。固件已定义 GPIO13 并实现普通 GPIO 开关，初始化为低电平，网页直接开/关；不使用阻塞延时、PWM 音量或自动报警音，重启恢复静音。

驱动外围三只电阻的用途如下：

- **R29 为基极限流。** 以 GPIO 高电平 3.3 V、基射压降 0.8 V 估算，R29 电流约 `(3.3−0.8)/1k = 2.5 mA`，扣除 R30 电流约 0.08 mA 后，流入 Q1 基极约 2.4 mA。1 kΩ 可作为调试起点，需在实际负载下验证 Q1 导通压降，不能由三极管放大倍数直接保证饱和。
- **R28 是并联负载，不给蜂鸣器限流，也不下拉 Q1 基极。** 忽略 Q1 导通压降时，其电流约 `3.3/470 = 7.0 mA`，功率约 `3.3²/470 = 23 mW`。若没有明确的泄放或消音用途，建议先设为不装，避免额外耗电；当前仍加入 BOM。
- **R30 已提供基极下拉。** 10 kΩ 接在 Q1 基极与发射极之间，使 GPIO 复位或高阻期间基极有明确的低电平。R28 与它的作用不同。

D7 当前极性及 C26 的电源去耦连接与低侧驱动方向一致。实物还需核对所购 SS8050 的封装脚序，并在上电、复位、连续鸣叫和显示刷新同时发生时检查误鸣与电源波动。

## 5. 双路隔离 RS485（原理图第 3 页）

### 5.1 通道结构

U5 为第一路、U7 为第二路，两路均为 ISO3082DWR。逻辑侧使用 3V3/GND，总线侧使用 A5V/AGND。ISO3082 为半双工器件，额定最高数据率 200 kbit/s；常用的 9600、19200、38400、115200 bit/s 在该上限内，实际可用距离与速率仍受布线和负载影响。[TI ISO3082 数据手册](https://www.ti.com/lit/ds/symlink/iso3082.pdf)

| 功能 | 第一路：U5 | 第二路：U7 |
| --- | --- | --- |
| 固件 UART 外设 | UART1 | UART2 |
| MCU TX | GPIO17 → 485_TX1 | GPIO11 → 485_TX2 |
| MCU RX | GPIO18 ← 485_RX1 | GPIO12 ← 485_RX2 |
| 方向控制 | GPIO21 → 485_REDE1 | GPIO14 → 485_REDE2 |
| 外部 A/B | 485A1 / 485B1 | 485A2 / 485B2 |
| CN1 引脚 | 3 / 4 | 1 / 2 |

ISO3082 的 D（6 脚）接发送数据，R（3 脚）输出接收数据；A、B 分别为 12、13 脚。逻辑侧供电脚为 VCC1（1 脚），总线侧为 VCC2（16 脚）。

### 5.2 电阻、电容及保护器件

以下为工程中的**实际装配参数**，位号已经随本版更新，不沿用早期版本的编号。

| 用途 | 第一路位号 | 第二路位号 | 当前参数及连接 |
| --- | --- | --- | --- |
| TX 串联电阻 | R13 | R20 | 100 Ω，1%，0.1 W，位于 MCU TX 与 D 脚之间 |
| RX 串联电阻 | R16 | R23 | 100 Ω，1%，0.1 W，位于 R 脚与 MCU RX 之间 |
| A 线串联电阻 | R14 | R21 | 22 Ω，1%，0.1 W |
| B 线串联电阻 | R17 | R24 | 22 Ω，1%，0.1 W |
| A 线上拉 | R12 | R19 | 470 Ω，5%，0.1 W，拉到 A5V |
| B 线下拉 | R18 | R25 | 470 Ω，5%，0.1 W，拉到 AGND |
| A/B 终端电阻 | R15 | R22 | 120 Ω，5%，0.125 W，直接跨接接口侧 A/B |
| 方向控制下拉 | R26 | R27 | 10 kΩ，1%，0.1 W，接主控 GND |
| A/B 对地电容 | C16、C17 | C22、C23 | 各 1 nF，接 AGND，位于 22 Ω 电阻的收发器侧 |
| 逻辑侧去耦 | C18 | C24 | 100 nF，3V3 对 GND |
| 总线侧去耦 | C19 | C25 | 100 nF，A5V 对 AGND |
| 总线 TVS | D5 | D6 | SM712，公共端接 AGND，两者均已加入 BOM |

470 Ω 上拉、下拉为总线提供空闲偏置。22 Ω 电阻用于限制瞬态电流并抑制振铃，也会造成发送幅度损失；1 nF 电容增加了总线电容负载，因此长线和最高使用波特率需要联合验证。

R15、R22 已位于 22 Ω 串联电阻之后的接口侧。终端应按实际总线拓扑配置，通常只在物理总线两端安装；若本板位于总线中间，应调整相应终端的装配。偏置电阻也需与外部设备的偏置统一规划，避免同一物理总线重复配置过多组。[TI RS485 设计指南](https://www.ti.com/lit/an/slla272d/slla272d.pdf)

建议后续将 R15、R22 的采购规格改为 **120 Ω、1%、至少 0.25 W**，增加精度与功率余量。当前工程仍为 5%、0.125 W，本文没有把这一建议记为已修改。

### 5.3 收发方向

每路的 DE 和低有效接收使能 `/RE` 接到同一个 485_REDE 网络。

| 方向 GPIO 电平 | DE | /RE | 状态 |
| --- | --- | --- | --- |
| 0 | 关闭发送 | 开启接收 | 接收状态，驱动器不占用总线 |
| 1 | 开启发送 | 关闭接收 | 发送状态，本机不通过 R 脚接收回显 |

R26、R27 在主控 GPIO 尚未主动驱动时下拉方向节点，建立默认接收状态。固件初始化应先保证方向低电平，发送前置高，等待最后一个停止位发送完成后再置低；使用 ESP-IDF 半双工模式时，应核对 RTS 实际引脚电平与此表一致。

### 5.4 CN1：两种外部引脚定义

| CN1 针号 | 网络 | 功能 |
| --- | --- | --- |
| 1 | 485A2 | 第二路 RS485 A |
| 2 | 485B2 | 第二路 RS485 B |
| 3 | 485A1 | 第一路 RS485 A |
| 4 | 485B1 | 第一路 RS485 B |

CN1 没有电源针和独立地针。两组 A/B 可兼容同一设备的不同引脚定义：此用法下，应用按设备类型向 UART1 或 UART2 发请求，未选通道保持不发送。这里的选择由两套独立收发器实现，没有模拟开关参与。

当前固件也支持两路分别接入独立总线并行运行 Modbus；两路均初始化，独立管理方向、队列、锁及通信参数。并行运行不表示可将两套收发器并到同一物理总线同时发送。具体使用方式应与外部线束及设备连接一致。

外部线束必须满足已确认的条件：未使用的两针不带 12～15 V 电源。接线时还应按对端实际 A/B 定义核对极性，并确认外部设备与本板通信侧的参考地关系。

## 6. CN2 隔离逻辑串口（原理图第 3 页）

U6 为 CA-IS3722HS，提供两个方向相反的数字隔离通道。主控侧 VDDA 为 3V3、GNDA 为 GND；外部侧 VDDB 从 CN2 第 1 针输入，GNDB 接 AGND。C20、C21 分别为两侧的 100 nF 去耦。

| CN2 针号 | 网络/连接 | 相对本板的方向 | 外部连接 |
| --- | --- | --- | --- |
| 1 | U6 VDDB | 电源输入 | 外部设备的逻辑电源 |
| 2 | ATXD → U6 VI1 | 数据输入 | 接外部设备 TX |
| 3 | U6 VO2 → BTXD | 数据输出 | 接外部设备 RX |
| 4 | AGND | 参考地 | 接外部设备逻辑地 |

发送路径为 GPIO43 / ESP_TXD → U6 VI2（3 脚）→ VO2（6 脚）→ CN2 第 3 针。接收路径为 CN2 第 2 针 → U6 VI1（7 脚）→ VO1（2 脚）→ GPIO44 / ESP_RXD。

VDDB 的工作范围为 2.5～5.5 V，应选用与外部设备信号电平一致的电源，常见为 3.3 V 或 5 V；CN2 第 1 针不是本板向外提供的电源输出。[CA-IS3722HS 厂商资料](https://e.chipanalog.com/products/interface/digital/sdi/1085)

CN2 是逻辑电平 UART，没有 RS232 电平变换，也不是 RS485 差分口。GPIO43/44 同时是芯片默认 UART0 引脚，启动阶段可能在 GPIO43 输出 ROM 启动字节，外部协议应能忽略这些上电数据。
当前应用使用 UART0 驱动 CN2；下载及应用日志保持 USB Serial/JTAG。

## 7. LCD 与电容触摸（原理图第 4 页）

### 7.1 H1 接口

LCD 模块为 3.5 英寸 ST7796S + GT911，原生像素排列为 320 × 480；现有固件配置为 480 × 320 横屏。显示通过 SPI，触摸通过 I²C，二者共用模块 RES 复位信号。依据为 [LCD 模块资料目录](LCD/中景园ZJY350S11CTG21电容触摸技术资料-ST7796) 内的规格书及模块原理图。

| H1 针号 | 原理图网络 | MCU GPIO | 功能 |
| --- | --- | --- | --- |
| 1 | GND | — | 主控侧地 |
| 2 | 3V3 | — | 模块 3.3 V 电源 |
| 3 | LCD-SPI-SCLK | 5 | SPI 时钟 |
| 4 | LCD-SPI-MOSI | 1 | SPI 写数据 |
| 5 | LCD-RST | 10 | LCD 与 GT911 共用低有效复位 |
| 6 | LCD-DC | 3 | LCD 数据/命令选择 |
| 7 | LCD-SPI-CS | 4 | LCD 片选 |
| 8 | LCD-BL | 6 | 背光控制，可使用 PWM |
| 9 | TP-SCL | 7 | GT911 I²C 时钟 |
| 10 | TP-SDA | 8 | GT911 I²C 数据 |
| 11 | TP-INT | 9 | GT911 中断及复位阶段地址选择 |
| 12 | LCD-SPI-MISO | 2 | 调试预留；标准 11 针模块不接此针 |

H1 使用 12 针是有意预留设计。普通 11 针模块使用前 11 针，第 12 针不能直接视为模块已提供 SPI 读回信号；现有固件将 SPI MISO 配置为未使用。

### 7.2 背光与触摸初始化

模块资料中的背光由模块内部晶体管驱动，H1 第 8 针输入的是控制信号，GPIO6 不直接承担 LED 背光供电电流。控制高电平点亮，可通过 PWM 调亮度；模块内部偏置可能使背光在固件初始化前亮起，最终启动亮度以实物为准。

模块原理图包含 SCL、SDA 到 3.3 V 的上拉，模块内部数值为 4.7 kΩ。主板未单独绘制这两只上拉，替换模块时需确认新模块是否自带。

GT911 的 7 位 I²C 地址可为 `0x5D` 或 `0x14`，通过复位阶段 INT 电平选择。正常运行时 INT 用作输入中断；驱动需要先完成地址选择，再切换引脚方向。详细时序见 [GT911 手册](<LCD/中景园ZJY350S11CTG21电容触摸技术资料-ST7796/01-规格书与芯片手册/01-规格书与芯片手册/电容触控芯片GT911 Datasheet_20130319.pdf>)。

GPIO10 同时复位显示和触摸，因此启动时应协调初始化。触摸已经工作后再次拉低 LCD-RST，会同时复位 GT911；此时需重新处理触摸地址、配置与中断。现有显示驱动在首次统一硬复位后使用 LCD 软件复位，避免无意重置触摸。

## 8. GPIO 和 UART 资源总表

以下数字均为 **GPIO 编号，不是模组焊盘编号**。

| GPIO | 当前用途 | 说明 |
| --- | --- | --- |
| 0 | BOOT | 启动配置引脚 |
| 1、2 | LCD MOSI、预留 MISO | GPIO2 接 H1 第 12 针 |
| 3、4、5、6 | LCD DC、CS、SCLK、BL | GPIO3 同时涉及启动配置 |
| 7、8、9 | 触摸 SCL、SDA、INT | INT 在复位阶段还用于选择地址 |
| 10 | LCD / 触摸复位 | 两者共用 |
| 11、12、14 | 第二路 RS485 TX、RX、REDE | UART2；GPIO14 已不再空闲 |
| 13 | 有源蜂鸣器控制 | 经 R29 1 kΩ 驱动 Q1，R30 10 kΩ 下拉，固件上电 LOW、网页开关 |
| 15、16 | 32.768 kHz 晶振 | 安装并使用晶振时不再作为普通 GPIO |
| 17、18、21 | 第一路 RS485 TX、RX、REDE | UART1 |
| 19、20 | USB D−、D+ | 保留用于 USB |
| 35、36、37 | 图中未连接 | N16R8 模组内部 Octal PSRAM 使用，不能分配给其他外设 |
| 38、39、42 | 图中未连接 | 扩展候选；使用调试接口时需核对复用关系 |
| 40 | KEY2，触摸开关 | 低有效，30 ms 消抖，稳定按下后长按 2 秒切换一次；上电默认触摸开启 |
| 41 | KEY1，保留输入 | 低有效，按下/松开各稳定 200 ms 才更新状态，无业务动作 |
| 43、44 | CN2 串口 TX、RX | 应用使用 UART0；控制台不占用业务 UART |
| 45、46 | 图中未连接 | 启动配置相关，扩展前核对上电电平 |
| 47、48 | 图中未连接 | 扩展候选，需按实际模组完整型号核对可用性及电压域 |

### 8.1 当前固件资源分配

硬件连线决定使用哪些 GPIO，UART0/1/2 外设编号由固件配置。当前 [固件说明](../fireware/README.md)、[引脚定义](../fireware/components/board_drivers/include/board_pins.h)、[RS485 驱动](../fireware/components/board_drivers/rs485.c) 和 [CN2 串口驱动](../fireware/components/board_drivers/serial_port.c) 已对应下表：

| 功能 | 当前固件分配 | 运行方式 |
| --- | --- | --- |
| RS485 第一路 | UART1，GPIO17/18/21 | 充电器 1 独立任务；通用 Modbus API 保留 |
| RS485 第二路 | UART2，GPIO11/12/14 | 充电器 2 独立任务，与第一路并行 |
| CN2 隔离串口 | **UART0**，GPIO43/44 | 独立收发，默认 115200、8N1 |
| 下载与日志 | USB Serial/JTAG | 继续使用 USB，避免占用业务 UART |

两路 485 各自持有事件队列、事务锁、帧间隔及串口配置；一路超时不会阻塞另一条总线。
默认均初始化且不自动发送，配置双路只读示例后，各自创建一个任务轮询独立配置的从站。
具体通信参数必须与各自设备一致；实机并行收发尚待样机验证。

当前 `fireware` 使用 ESP-IDF 6.1，项目依赖已完整内置，旧参考代码目录可删除。
具体 GPIO、触摸芯片、UART 分配以本版电路与实际固件为准；源码来源与工具依赖见
[固件依赖说明](../fireware/DEPENDENCIES.md)。

GPIO40 的触摸开关仅屏蔽输入，不复位 GT911、不关闭 LCD；关闭期间继续读取和清除触摸帧。
重新开启前丢弃挂起帧，已按住屏幕的手指需松开再开始新手势，避免旧触点重放；重启恢复开启。
GPIO41 只读取滤波后的按键状态，不产生业务动作或长按事件。

GPIO13 蜂鸣器已接入固件，默认静音，接口为 `buzzer_init/set/is_on`。充电控制、网页和网络已移植到 `fireware/components/charger`；两路分别控制独立充电器，运行设定每 15 秒写入，开关机与保护立即执行。实体旧屏幕 UI 和 EC11 暂不移植，LCD 保留 LVGL benchmark。详见 [充电控制说明](../fireware/CHARGER.md)。

## 9. 装配状态与尚待验证项目

### 9.1 工程装配标记

| 器件 | 当前工程状态 | 制作含义 |
| --- | --- | --- |
| D5、D6 | 加入 BOM | 两路 SM712 均进入物料清单 |
| R26、R27 | 加入 BOM，10 kΩ | 两路方向控制下拉已落实 |
| R15、R22 | 加入 BOM，120 Ω / 5% / 0.125 W | 接口侧终端，是否装配取决于总线位置 |
| BUZZER1、Q1、D7、C26、R28、R29、R30 | 均加入 BOM | 新增蜂鸣器支路，GPIO13 及基极下拉已落实；R28 不装仍为后续建议 |
| R1 | 不加入 BOM | 1 MΩ 晶振跨接电阻作为预留 |
| SW1、SW2、SW3 | 不加入 BOM | 备用按键封装 |
| H1 | 不加入 BOM | 需在人工采购/装配安排中明确 12 针排母；该标记不改变接口的设计用途 |

“不加入 BOM”是当前工程导出属性，不自动代表实物永不安装；尤其 H1 是正常使用 LCD 所需的连接位置。

### 9.2 建议与验证范围

| 项目 | 当前事实 | 后续工作 |
| --- | --- | --- |
| 蜂鸣器固件 | GPIO13 默认关闭及网页开关已实现 | 上板确认上电静音、电平与驱动电流 |
| 蜂鸣器关断与功耗 | R30 10 kΩ 基极下拉已加入，R28 470 Ω 仍并联蜂鸣器 | 无明确泄放用途时 R28 可不装；实测上电静音、驱动压降及支路电流 |
| 终端电阻规格 | R15/R22 仍为 5%、0.125 W | 建议选 1%、至少 0.25 W，并按总线两端配置装配 |
| 完整主控型号 | 硬件名称未标容量后缀，固件目标 N16R8 | 采购前统一型号与 Flash/PSRAM 配置 |
| 双路串口软件 | 已实现 UART1/UART2 双路 Modbus、CN2 UART0，编译与主机测试通过 | 按第 8 节配置两台从站，实测并行收发及一路断线时的独立性 |
| 隔离电源余量 | U2 标称 400 mA；LCD 约 61 mA，当前蜂鸣器支路鸣叫时再预算约 40 mA | 测试最重负载下的启动、3V3 压降及 U3 温升 |
| EN 复位时序 | R9 10 kΩ、C13 100 nF | 验证慢上电、快速断电重启和负载突变下的可靠启动 |
| 外部低速晶振 | X1 标称负载 12.5 pF，C8/C9 各 12 pF | 若启用，验证起振与频偏后确定电容参数 |
| PCB 实现 | 工程已含器件与网络数据，本轮未完整评审布局布线 | 检查隔离边界、供电回路、接口保护器件位置、USB、晶振及蜂鸣器电流回路 |

上述内容是文档编写时的待办状态，不是实测失败记录。USB 接入隔离输出侧及 H1 额外预留 MISO 已按设计意图记录，不列为连接错误。

## 10. 样机上电与调试顺序

1. **断电检查。** 核对实板蜂鸣器接 GPIO13、R30 接在 Q1 基极与发射极之间。核对 CN3 极性、二极管方向、U2 引脚、主控型号及实际装配；检查电源对地短路，确认主控 GND 与 AGND 没有非设计连接。
2. **单独验证 VIN 供电。** 使用有电流限制的 12 V 电源接 CN3。相对 AGND 测量 A5V；相对主控 GND 测量 5V 和 3V3。记录轻载、正常负载及启动时的电压。
3. **USB 下载与日志。** 按需要验证 USB 单独临时供电，检查枚举和下载。USB 单供电阶段只验证主控侧功能。
4. **按键、LCD 与触摸。** 完成 GPIO10 共用复位及 GT911 地址选择，检查横屏、背光与触摸坐标。KEY2/GPIO40 长按 2 秒开关触摸，保持按住只触发一次，重启默认开启；KEY1/GPIO41 仅在电平稳定 200 ms 后更新状态。关闭及重新开启触摸时按住屏幕，检查旧手势不会误触发。
5. **CN2 串口。** 向 CN2 第 1 针提供与外部 UART 一致的逻辑电源，第 4 针接外部逻辑地；对端 TX 接第 2 针、RX 接第 3 针。核对上电字节及双向通信。
6. **RS485 第一路。** 保持 VIN 供电，使用 CN1 第 3/4 针，核对终端配置、A/B 极性和 GPIO21 收发切换，先以较低波特率完成通信。
7. **RS485 第二路及并行测试。** 使用 CN1 第 1/2 针，验证 GPIO14 默认接收及发送结束回到接收。分别接入两条独立总线后运行双路只读示例，拔掉一路应仅使该路超时，另一路继续通信；仅使用兼容线束时确认选择正确的通道。
8. **蜂鸣器。** 烧录 GPIO13 控制固件后，先保持输出低，检查上电和复位时是否静音，再测试短响、长响及停止；测量 Q1 导通压降、支路电流与 3V3 波动。
9. **整机负载测试。** 在实际线缆、目标波特率、显示刷新、蜂鸣器鸣叫及无线功能等实际负载下，检查误码、复位、3V3 瞬态和电源温升。

跨隔离边界测量时，应核对仪器各通道地夹是否共地，避免测量接线把 GND 与 AGND 短接。此处给出调试步骤，未预填任何样机测试结果。

## 11. 文件与资料索引

| 资料 | 用途 |
| --- | --- |
| [原理图 PDF](PCB/SCH_Schematic1_2026-10-04.pdf) | 四页电路连接、信号网络、接口引脚 |
| [EDA 专业版工程](PCB/ProDoc_Board1_2026-10-04.epro2) | 器件属性、BOM 标记、实际参数及工程编辑 |
| [LCD 引脚图](LCD/3.5寸LCD尺寸和引脚.png) | 模块尺寸和接口位置 |
| [LCD 模块原理图压缩包](LCD/中景园ZJY350S11CTG21电容触摸技术资料-ST7796/02-原理图.zip) | 共用复位、背光驱动、模块内 I²C 上拉 |
| [LCD 芯片与模组资料目录](LCD/中景园ZJY350S11CTG21电容触摸技术资料-ST7796/01-规格书与芯片手册/01-规格书与芯片手册) | ST7796S、GT911 和屏幕规格书 |
| [现有固件](../fireware/README.md) | 当前软件配置、驱动接口与构建方法 |
| [固件依赖清单](../fireware/DEPENDENCIES.md) | 已内置源码、资源、许可及独立构建方法，无需旧参考目录 |
| [项目文档总入口](../readme.md) | 全部正式文档的索引与维护规则 |

为区分同名文件的再次导出，本版文档核对的源文件 SHA-256 如下：

```text
SCH_Schematic1_2026-10-04.pdf
6d988b33f0d29e5ac5473c03b552005e6d200fcd27e2aa649493e39553dc1181

ProDoc_Board1_2026-10-04.epro2
423db2c4a826e2c275666e31198c6bc53c08a92acbb3958e29e164440aad8acc
```

后续若更改位号、GPIO、终端规格、供电路径或 UART 分配，应同步更新本文对应表格与源文件版本。

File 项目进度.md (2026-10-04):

# 项目进度

更新日期：2026-10-05。目标模组：**ESP32-S3-WROOM-1U-N16R8**。
固件目录：`fireware`；使用本机 **ESP-IDF 6.1** 和配套 Xtensa 工具链。
当前固件基线提交：`2619100`（双路充电控制与网页网络移植）。

## 当前阶段

已完成基础驱动、双路充电控制、网页及网络功能的软件移植，已通过编译和主机测试，
目前处于实板联调前阶段。

**LCD 保留 LVGL benchmark，暂未移植旧屏幕 UI。** 实体 LCD 当前为 480×320 横屏，
上电运行 LVGL 8.4 benchmark；还没有用于操作充电业务的实体触摸界面。
EC11 编码器暂未移植，后续计划使用 LVGL 触摸屏完成本地充电操作。
网页充电控制界面已移植，可通过网页分别操作两路充电器。

## 功能进度

下表的“已实现”表示软件实现已完成，实板行为仍需按验收步骤验证。

| 模块 | 当前进度 | 当前行为或边界 |
| --- | --- | --- |
| SPI LCD 驱动 | 已实现 | ST7796S，480×320 横屏，背光控制；LCD 保留 LVGL benchmark |
| LVGL 基础适配 | 已实现 | LVGL 8.4、显示刷新、GT911 输入和 benchmark 资源已内置 |
| 实体屏幕充电 UI | 暂未移植 | 未移植旧 LovyanGFX 屏幕 UI；后续实现 LVGL 触摸业务界面 |
| EC11 编码器 | 暂未移植 | 当前不用于业务操作 |
| GT911 触摸 | 已实现 | 横屏坐标映射；上电默认开启触摸 |
| GPIO40 按键 | 已实现 | 长按 2 秒切换触摸开启/关闭，一次按住只切换一次 |
| GPIO41 按键 | 已实现 | 备用输入，按下和松开均作 200 ms 稳定滤波，仅查询状态 |
| GPIO13 蜂鸣器 | 已实现 | 高电平响、低电平停，上电默认关闭，网页提供开关 |
| CN2 隔离串口 | 已实现 | UART0，TX43/RX44，默认 115200、8N1 |
| 双路 RS485 | 已实现 | UART1：TX17/RX18/DE21；UART2：TX11/RX12/DE14，独立任务与收发资源 |
| 充电器协议 | 已移植 | demo 厂家 RTU 方言接入两路 485；通用 Modbus API 保留 |
| 双路充电控制 | 已移植 | 两台充电器独立配置和运行；CC/CP、预设、爬坡、保护、统计、NVS 保存 |
| 写命令时序 | 已实现 | 运行设定每路每 15 秒写入；首次启动预装设定、开关机及保护停机立即执行 |
| 网页界面 | 已移植 | 通道选择、双路总览、参数、预设、波形、配色、状态与停止操作 |
| 网络与升级 | 已移植 | Wi-Fi AP/STA、配网、断线重连、SNTP、mDNS、PIN、网页重启和双分区 OTA |
| 工程依赖 | 已整理 | 项目依赖与网页资源均在 `fireware` 内，构建不依赖 `demo` 或旧参考目录 |
| 文档与 Git | 已整理 | 根目录 `readme.md` 管理文档索引，编译产物由 Git 忽略规则排除 |

## 已完成的验证

- 本机 ESP-IDF 6.1 主工程编译通过。
- 仅包含固件输入的独立副本从零构建通过。
- 原有 19 组驱动测试和新增 14 组充电控制测试通过，共 33 组主机测试。
- 内嵌网页脚本检查及使用模拟数据的浏览器预览检查通过。
- LVGL、mDNS 依赖校验和 Git 暂存内容校验通过。

上述结果不代表实板验收完成。上一轮验证未检测到串口设备，尚未完成本轮实板烧录、
双路充电器通信、电气时序、蜂鸣器、真实网络与 OTA 测试，也没有实测 LCD FPS 记录。

## 后续工作

1. **实板联调。** 完整烧录后检查 LCD/触摸、GPIO40/41、GPIO13 和 CN2 串口。
2. **双路充电验收。** 核对两台设备协议和串口参数，实测 15 秒写入间隔、开关机应答、
   一路断线时另一路的独立性，以及保护停机和关机重试。
3. **网络与 OTA 验收。** 检查 AP/STA、配网、重连、mDNS、参数保存及 OTA 成功/失败路径。
4. **LVGL 触摸业务界面。** 后续按确认的界面设计替换 benchmark，接入现有充电服务接口，
   实现本地选路、参数设置、运行状态和启停操作；这部分目前尚未开始实现。

首次从旧单应用分区固件升级到当前双 OTA 分区版本，需通过 USB 完整烧录新分区表和应用。

## 相关文档与维护

- [项目文档总入口](readme.md)
- [固件使用与驱动 API](fireware/README.md)
- [双路充电控制、网页与验收步骤](fireware/CHARGER.md)
- [固件依赖及独立构建](fireware/DEPENDENCIES.md)
- [硬件原理图说明](hardware/原理图说明.md)

每次完成一个阶段后更新本页日期、功能状态和验证记录。实板验证通过后再将对应项目标为
“实板已验证”，并记录使用的硬件版本、测试条件及结果；新触摸 UI 完成前保留本页的 LCD 状态说明。

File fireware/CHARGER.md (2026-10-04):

# 双路充电控制与网页

## 移植范围

以 demo 的 Arduino 充电控制程序为行为与报文来源，改为本机 ESP-IDF 6.1 原生组件。
所有源文件、网页、mDNS 与许可均在 `fireware` 内；编译和运行不读取 `demo`。
实体屏幕继续运行 480×320 LVGL benchmark，未移植旧 LovyanGFX 屏幕 UI、EC11 编码器
或旧板引脚。后续 LVGL 触摸 UI 可直接调用 `charger_service.h`，不必重写协议和控制任务。

迁移了 CC/CP、5 组预设、启动电流爬坡、功率/停充电流保护、AH/WH/次数、参数持久化、
地址查询/扫描、网页画布与键盘、波形、25 色配色、Wi-Fi 配网、PIN、SNTP、mDNS、重启和 OTA。
网页新增两路选择与总览，各路参数、地址、运行状态、保护、统计、锁定完全独立。
配色、网络、网页端口、PIN 和 GPIO13 蜂鸣器属于整块控制板。

浏览器通过控制板 HTTP 服务控制板上两路 485。旧网页中的 Web Serial/DTU 直连模式不再显示，
以免绕过板上周期、保护和状态管理；旧网页中不同于 MCU 逻辑的开关机值也未沿用。
旧屏幕复位、编码器连按急停、PWM 音量和可调保活参数已移除，网页提供明确的停止按钮。

## 首次使用

1. 在 `fireware` 执行 `.\build.ps1 build`，然后通过 USB Serial/JTAG 完整烧录：

   ```powershell
   .\build.ps1 -IdfArgs @('-p', 'COM5', 'flash', 'monitor')
   ```

   COM5 换为实际端口。本次从旧 1 MB factory 表改为 `partitions.csv`：20 KiB NVS、
   8 KiB OTA 元数据、两个 4 MiB 应用槽。首次升级必须烧录新的分区表与应用，不能只用
   旧固件的 OTA/`app-flash`。烧录整套镜像也适用于未连接充电器时的升级。

2. 连接热点 **ChargerCtrl**，密码 **12345678**；访问 **http://192.168.4.1/**，
   自动跳转到默认网页端口 **8899**。初始控制 PIN 为 **1234**，网页可修改。
   STA 配网后同一网页也可经路由器分配的 IP 或支持 mDNS 的客户端 `http://charger.local/` 访问。
   AP 始终开启，避免尚未移植实体 UI 时失去配网入口。路由器连接失败每 15 秒重试，
   不影响两路充电任务。配网时需重新输入 Wi-Fi 密码，设备不通过 API 回显密码。

3. 两路默认各为 **9600、8N1、设备地址 0**。UART1：TX17/RX18/DE21；
   UART2：TX11/RX12/DE14。两路分别接两台充电器，不能把两组 A/B 并到同一总线。
   选择 `485-1` 或 `485-2` 后单独设置参数；串口格式在 menuconfig 分别配置。
   地址不同可在停止状态扫描或手填，扫描只展示结果，保存设置后才切换地址。
   切换后先向新地址请求停止，再允许启动。

4. 上电**不恢复充电运行**：两路先发关机请求并读取状态。网页显示 `已确认停止` 后可启动。
   没有设备或应答丢失时显示 `等待OFF应答`/离线，不把发送成功当成关机成功。
   已经尝试开机而尚未确认关闭时，禁止改地址、OTA 和重启。

5. GPIO13 为有源蜂鸣器开关：HIGH 响、LOW 停，初始化先输出 LOW。网页按钮可开/关，
   重启恢复关闭，不保存鸣叫状态；本版不自动鸣叫、不占用 LEDC、不提供 PWM 音量。
   GPIO40 长按 2 秒切换触摸、GPIO41 200 ms 只读滤波维持原行为。

## 两路控制和时序

- 每路独立任务、配置、锁、读写状态；一路超时不阻塞另一路的 UART 事务。
- 空闲时读取状态，**不周期写入电压/电流、不自动开机**。每次读取完成后约 500 ms 再读，
  单次收发超时参数为 250 ms；地址扫描逐项进行，不在 HTTP 请求中阻塞扫描。
- 启动时立即写入初始电压/电流，初始电流为 `min(1 A, 目标电流)`；确认写入后立即开机，
  只有开机应答正确才显示运行并计次。初始预装不等待 15 秒，以免启用充电器残留参数。
- **运行中电压/电流写命令每路间隔 15,000 ms**，从上一笔设定事务结束计时。
  修改设定只更新待发送值，下一个周期生效。任务调度或当时正在进行的读取可能带来少量延后。
  写入失败直接进入保护停机，不用密集重写设定值来掩盖故障。
- 开机、主动停止、保护停机不受 15 秒计时限制。已在执行的 UART 事务先结束，再处理停止。
  OFF 无应答时约每秒重试，继续显示未确认状态；通信恢复不会自动重新启动。
- 原 demo 的循环 ON 保活已移除，避免在停止竞争或周期外反复开机。所接充电器能否接受
  15 秒设定周期、是否另有厂家保活要求，需使用对应型号实板确认。
- 爬坡按经过的时间计算，默认每秒增加 0.05 A，在每次 15 秒写入时采样，所以线上的电流
  步进通常约为 0.75 A。降低目标电流也会生效。CC 的保护功率为目标 V×A；
  CP 与 demo 一样按 `目标电流 = 目标功率 / 目标电压` 计算，并非基于实测电压闭环调节。
- 两次连续实测功率超过对应已应答目标功率的 110%，触发 `PWR`；硬件状态位触发
  `OCP`/`SHORT`/`OTP`。尚未发送的较低目标不会提前造成误保护；绝对最大功率仍受当前配置约束。
- 停充电流保护先要求见过达到阈值的电流，且启动超过 10 秒，之后低于阈值触发 `TRKL`。
  设为 0 禁用。连续 3 次状态读取失败触发 `COMM`，启动写入/开机失败为 `START`，
  运行中设定写入失败为 `WRITE`。故障须重新人工启动，错误未消失时启动会被拒绝。
- AH 直接积分实测电流，WH 积分实测功率，不沿用旧 `WH/设定V` 的 AH 近似。
  无效读数和大于 2 秒的采样间隙不积分。每次成功启动清空本次 AH/WH，次数累加；
  运行中约每分钟及启动/确认停止时保存，突然断电最多丢失最近一分钟统计。
- 设置和统计用带版本的 NVS 数据保存；保存失败向网页报告错误。运行、锁定、触摸开关、
  蜂鸣器开关不持久化。锁定阻止改参数/启动，**停止始终允许**。

## 厂家 RTU 协议

`charger_codec.c` 单独实现 demo 方言，通用 `modbus_rtu` 的 `03/04/06/10` API 保留。
厂家协议中的地址 0 是有应答的单设备地址，不能当成通用 Modbus 广播。

| 操作 | CRC 之前的数据 | 正常应答 |
| --- | --- | --- |
| 状态读取 | `addr 03 00 01 00 03` | `addr 03 06 Vhi Vlo Alo Ahi Shi Slo CRClo CRChi` |
| 开机 | `addr 06 00 00 00 FF` | 8 字节完整回显 |
| 关机 | `addr 06 00 00 00 00` | 8 字节完整回显 |
| 电压/电流 | `addr 0F 00 01 00 02 Vhi Vlo Ahi Alo` | 前 6 字节回显 + CRC |
| 查询地址 | `DD DD 00 01` | `DD DD 00 01 00 addr CRClo CRChi` |

电压倍率 10、电流倍率 100；只有读取电流是小端。`0x0F` 无字节计数字段，
不是标准写线圈。所有响应检查长度、地址/功能、CRC，写入检查回显，异常帧不当成功。
状态低 4 位为 IDLE/BOOT/CHG/FULL/LIM；`0x40/0x20/0x10` 为 OCP/SHORT/OTP。
沿用 demo MCU 侧规则，`0x80` 不当作 OVP，避免 `0x0082/0x2082` 正常状态误停机。

## 网页与 API

网页本地嵌入，无 CDN、字体或 JS 网络依赖；主界面保留 demo 的网页画布风格，
这不是实体 LCD UI。选路时清空波形并取消未确认操作；旧通道响应不会覆盖新通道。
波形保留当前页面最近 240 个有效样本，断线期间不补造测量值，横轴按样本秒近似显示。

除根页面和 OTA 专用入口外，API 要求明确的 `ch=1` 或 `ch=2`。
只读状态/参数公开，修改操作统一 POST，并通过 `X-Charger-PIN` 请求头认证；
也兼容 `pin` 表单/查询字段。未移植旧 demo 的固定管理员后门。
非法参数返回 400，PIN 错误 401，运行状态冲突或保存失败 409，前端会显示错误。

| API | 方法与参数 |
| --- | --- |
| `/state` | GET；含测量、在线/停止确认、待写倒计时、统计、保护、扫描状态 |
| `/settings` | GET；POST：`port,maxV,maxA,maxP,rampMs,rampSt,addr`；编辑系统设置前停止该路 |
| `/setparam` | POST：`field=setV/setA/trickle/pwrMax,val`；CP 电流与 CC 功率由公式计算 |
| `/btn` | POST：`id=start/stop/cc/lock/clr/clrall`；明确 start/stop，不用远程盲切换 |
| `/presets` | GET；5 组 `[V,A]` |
| `/preset`、`/preset_set` | POST：`n=1..5`；编辑另加 `v,a` |
| `/scan` | POST；仅该路非运行时允许；查询后最多扫描 0～247 |
| `/theme`、`/theme/reset` | GET 当前 25 色；POST `c=rrggbb,...` 保存，reset 恢复 |
| `/wifiget`、`/wifisave` | GET 需 PIN，仅返回 SSID；POST `ssid,pass` 配网 |
| `/pinset` | POST：用当前 PIN 认证，`new` 为 4～16 字节新 PIN |
| `/buzzer` | POST：`on=0/1`；全局 GPIO13 |
| `/reboot` | POST；两路都确认停止且未扫描时接受 |
| `/update` | POST；原始应用 `.bin` 二进制请求体，不使用 multipart；需要 PIN |

网页端口修改保存后重启生效；80 端口跳转和 mDNS 服务发布指向本次实际监听端口。
OTA 仅接受应用文件 `build/esp32s3_basic_drivers.bin`，最大 4 MiB；按 ESP-IDF 校验镜像后
才切换启动槽，错误/中断会终止升级并返回失败，不报告假成功。升级期间阻止新的启动请求。
需两台充电器均确认停止；设备未连接而无法获取 OFF 应答时可通过 USB 完整烧录。

## 验证与实板验收

```powershell
& 'C:\Espressif\tools\python\v6.1\venv\Scripts\python.exe' tests/test_charger.py
node tests/test_web.cjs
& 'C:\Espressif\tools\python\v6.1\venv\Scripts\python.exe' tests/check_dependencies.py
```

充电测试把真实 service/codec/policy 编译为主机程序，模拟时钟和 UART 应答：双路周期、
低电流目标、启动失败、关机重试、停止与启动竞争、通信故障、功率/停充/硬件故障保护、
维护互斥、锁定、存储失败、地址扫描、AH/WH 积分均有覆盖。网页测试执行实际内嵌 JS，
检查 DOM 绑定、选路、命令/认证、错误反馈、旧响应抑制与画布调用。
通用 Modbus、双路 UART 并发、坐标、按键和触摸防误触原有 19 组测试保留。

以上属于编译和主机模拟，不能替代真实 Wi-Fi、RTU 时序、充电器电气行为和 OTA 掉电验证。
本轮未检测到串口设备，没有烧录或声称实板充电成功。上板时分别确认：

1. GPIO13 上电/复位静音及网页开关；LCD benchmark、GPIO40/41 正常。
2. 两台充电器的地址、波特率、厂家报文与 CRC；逻辑分析仪确认两路 DE 和 15 秒设定间隔。
3. 两路不同设定同时运行，停止一路不影响另一路；拔掉一路后的 COMM 保护与重连不自启。
4. 开机/关机应答丢失、降流、功率与停充阈值、保护后 OFF 重试。
5. AP/STA 配网、断网重连、mDNS、端口修改、PIN、NVS 重启保存和两槽 OTA 成功/失败路径。

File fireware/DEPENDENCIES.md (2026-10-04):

# 工程依赖与源码来源

本工程的全部项目源码、字体、图片、Kconfig、构建脚本及测试均在 `fireware` 内。
旧参考目录 `ref-code` 仅是历史移植来源，删除它不会影响编译或运行；没有符号链接、
相对包含或构建步骤指向该目录。`hardware` 是设计资料，也不是构建输入。
充电业务与网页已从 `demo` 移植到本地组件，`demo` 同样不是构建输入。

## 项目内依赖

| 内容 | 本地位置 | 说明 |
| --- | --- | --- |
| 应用与任务 | [main](main) | LVGL benchmark、双路 Modbus 示例、按键及串口处理 |
| 本板驱动 | [board_drivers](components/board_drivers) | ST7796、GT911、GPIO、UART0、双 UART RS485 / Modbus |
| 双路充电控制与网络 | [charger](components/charger) | 原生 ESP-IDF 控制、NVS、Wi-Fi、HTTP、OTA，内嵌网页来自用户 demo 的移植 |
| mDNS 1.10.0 | [mdns](components/mdns) | Espressif 官方组件，Apache-2.0；源码、许可、校验表已内置 |
| LVGL 适配 | [board_lvgl](components/board_lvgl) | 显示刷新、触摸输入、时钟与 GUI 任务 |
| LVGL 8.4.0 核心、字体、图片与 benchmark | [lvgl](components/lvgl) | 原样内置，MIT 许可；不依赖组件管理器下载 |
| LVGL 许可与来源 | [LICENCE.txt](components/lvgl/LICENCE.txt)、[PORTING.md](components/lvgl/PORTING.md) | 保留原始许可、版本与提交信息 |
| LVGL 原始文件校验表 | [SOURCE_SHA256.json](components/lvgl/SOURCE_SHA256.json) | 398 个原始文件的 SHA-256；自编适配和 CMake 不在此表内 |
| 本机构建入口 | [build.ps1](build.ps1)、[idf_short_path.py](tools/idf_short_path.py) | 读取本机工具链环境，解决本目录中文路径问题 |
| 验证脚本 | [tests](tests) | 实际 C 协议、坐标、双路通信及按键/触摸策略测试 |

ST7796 初始化寄存器取自屏幕厂家的 SPI 示例，所需寄存器表已完整写入
`components/board_drivers/lcd_st7796.c`；运行时不读取原始示例或硬件压缩包。
GT911、UART/RS485、按键及 LVGL 板级适配均由本工程源码实现。

只包含当前启用的 LVGL core 和 benchmark；未包含其他 demo/examples，构建配置会阻止
误启用这些未内置目录。后续若新增第三方组件或资源，须将实际文件、版本与许可证一并
保存在工程内，并更新本表；不要重新引入对旧参考目录的依赖。

## 本机开发工具

- 固件编译：已安装 ESP-IDF **v6.1**，`C:\esp\v6.1\esp-idf`。
- 芯片工具链：Xtensa GCC **15.2.0**，来自本机 Espressif 安装器环境。
- Python：`C:\Espressif\tools\python\v6.1\venv\Scripts\python.exe`。
- 主机测试：已安装 MSVC 14.51 / Windows SDK 10.0.26100；只编译测试 DLL，
  不用于生成 ESP32 固件。测试不需要额外 pip 包。

SDK 和编译器继续使用本机安装，不复制到项目、不升级、不下载替代版本。
拷贝 `fireware` 到其他电脑后需安装相应工具，再调整 `build.ps1 -IdfProfile` 参数。

## 独立性验证

LVGL 校验表保留移植来源的 SHA-256；由于既有 Git 提交将 CRLF 转为 LF，校验脚本只容许
文本换行差异，其他字节仍须匹配。`.gitattributes` 固定 LVGL 文本检出为 LF，mDNS 按上游
原始字节存储；图片等二进制资源始终按原始字节校验。

```powershell
& 'C:\Espressif\tools\python\v6.1\venv\Scripts\python.exe' tests\check_dependencies.py
& 'C:\Espressif\tools\python\v6.1\venv\Scripts\python.exe' tests\check_dependencies.py --prepare-standalone
```

第二条命令在 `tests/build/standalone_<随机编号>` 创建只含固件输入的副本，不拷贝既有
`build` 或 `sdkconfig`，也不修改原始资料目录。在输出目录执行 `./build.ps1 build`
从零构建。副本包含充电控制、网页、mDNS 与 OTA 分区表，无 `demo`、旧参考目录或硬件资料。
可选的通用 Modbus 示例、不同奇偶校验及无 GUI 分支用 `tests/check_optional_build.py` 检查。

## 充电与 mDNS 来源

充电报文和业务、网页画布/样式移植自用户提供的
`____________copy_20260912223219.ino`，源文件 SHA-256：
`ac5d4724782fb9c4e88bc024d60ce33def6b69b3d5c998b2320fecf41d6ab6c6`。
源文件无需保留在构建目录；`components/charger` 已包含本轮所需实现与网页资源。
不引入 Arduino、LovyanGFX、WebServer、Preferences 或 Update 库。

mDNS 取自 [Espressif esp-protocols](https://github.com/espressif/esp-protocols/tree/98d79b16138b419751cce79a015f8b5b0b51bcc1/components/mdns)，
标签 `mdns-v1.10.0`，提交 `98d79b16138b419751cce79a015f8b5b0b51bcc1`。
保留组件源码、构建配置、文档与 Apache-2.0 LICENSE，不包含上游测试/示例；40 个文件
由 `components/mdns/SOURCE_SHA256.json` 校验。其 manifest 仅要求本机 IDF >= 5.0，
`dependencies.lock` 记录当前 IDF 6.1，无需下载额外组件。

测试新增使用本机 Node.js 执行内嵌网页脚本，无 npm 包；MSVC 编译真实充电 service/codec/policy
并用模拟 UART/时钟验证业务。固件始终由本机 ESP-IDF / Xtensa GCC 编译，不改装 SDK。

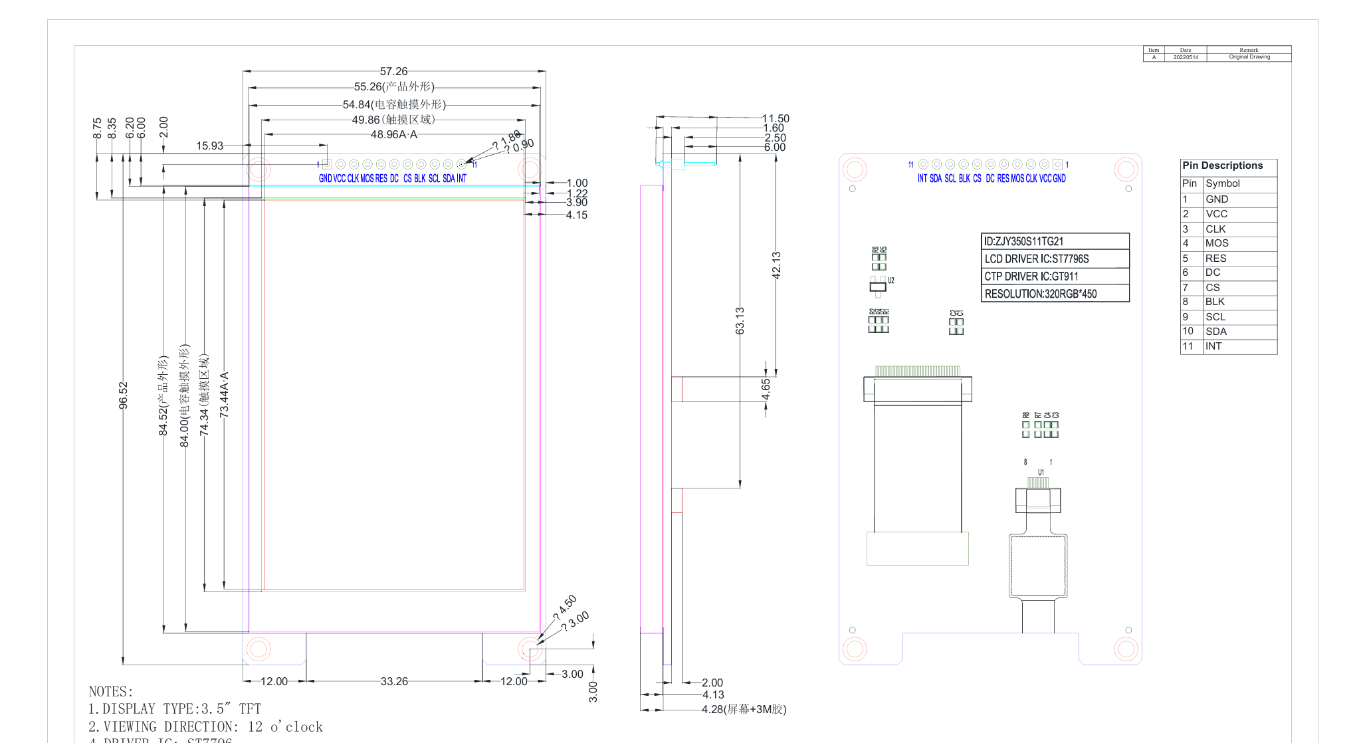
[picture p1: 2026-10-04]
hardware/LCD/3.5寸LCD尺寸和引脚.png

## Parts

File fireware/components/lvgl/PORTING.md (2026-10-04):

# Local LVGL 8.4.0

LVGL **8.4.0** is fully bundled in this directory. It was originally imported from
the old reference project; that project is no longer needed and may be deleted.
The imported manifest identifies upstream commit
`4495f428630cc1741bd8bfd977f080e8460e8e8d`. No upgrade was performed.

Unmodified files: `src/`, `demos/benchmark/`, `demos/lv_demos.h`, `lvgl.h`,
`Kconfig`, and `LICENCE.txt`. The MIT license is retained. `CMakeLists.txt` is the
local ESP-IDF component integration. Examples and other demos are deliberately
not bundled; enabling them produces a configuration error with this explanation.
All 398 original files are listed in [SOURCE_SHA256.json](SOURCE_SHA256.json).
Verify them with `python tests/check_dependencies.py` from the firmware root;
verification does not need the original reference project.

Configuration uses the original Kconfig via `CONFIG_LV_CONF_SKIP=y`; there is no
second `lv_conf.h`. The project's `sdkconfig.defaults` enables RGB565, benchmark,
compressed fonts, malloc/free with ESP-IDF PSRAM support, and USB console logs.
`LV_COLOR_16_SWAP` is disabled because `lcd_draw_rgb565()` performs the byte swap.

The separate `board_lvgl` component adapts LVGL 8's display and pointer callbacks
to the current ST7796 / GT911 drivers. It does not copy the reference board's
FT6336 / TCA9554 / AXP2101 dependencies. A 5 ms tick and a single GUI task drive
LVGL; synchronous SPI completion precedes `lv_disp_flush_ready()`.
Touch input is gated by the board driver. GPIO40's two-second hold toggles input;
the GUI callback resets a prior gesture on a mode change without synthesizing a
click. GPIO41 is a reserved, filtered input and is not bound to LVGL.

See the [dependency inventory](../../DEPENDENCIES.md) for local tools and the
standalone build procedure.

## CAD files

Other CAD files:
hardware/LCD/中景园ZJY350S11CTG21电容触摸技术资料-ST7796/01-规格书与芯片手册/01-规格书与芯片手册/模块结构图ZJY350S11CTG21.dwg
hardware/LCD/中景园ZJY350S11CTG21电容触摸技术资料-ST7796/01-规格书与芯片手册/01-规格书与芯片手册/ZJY350S11CTG21.dwg
hardware/LCD/中景园ZJY350S11CTG21电容触摸技术资料-ST7796/01-规格书与芯片手册/01-规格书与芯片手册/裸屏结构图LCM-ZJY350C4001(T).dwg

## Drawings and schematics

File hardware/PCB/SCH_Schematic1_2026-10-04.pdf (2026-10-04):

A | VIN+ | | | | | | | | | B0505S-2WR3 | | | | | | | | | | | A

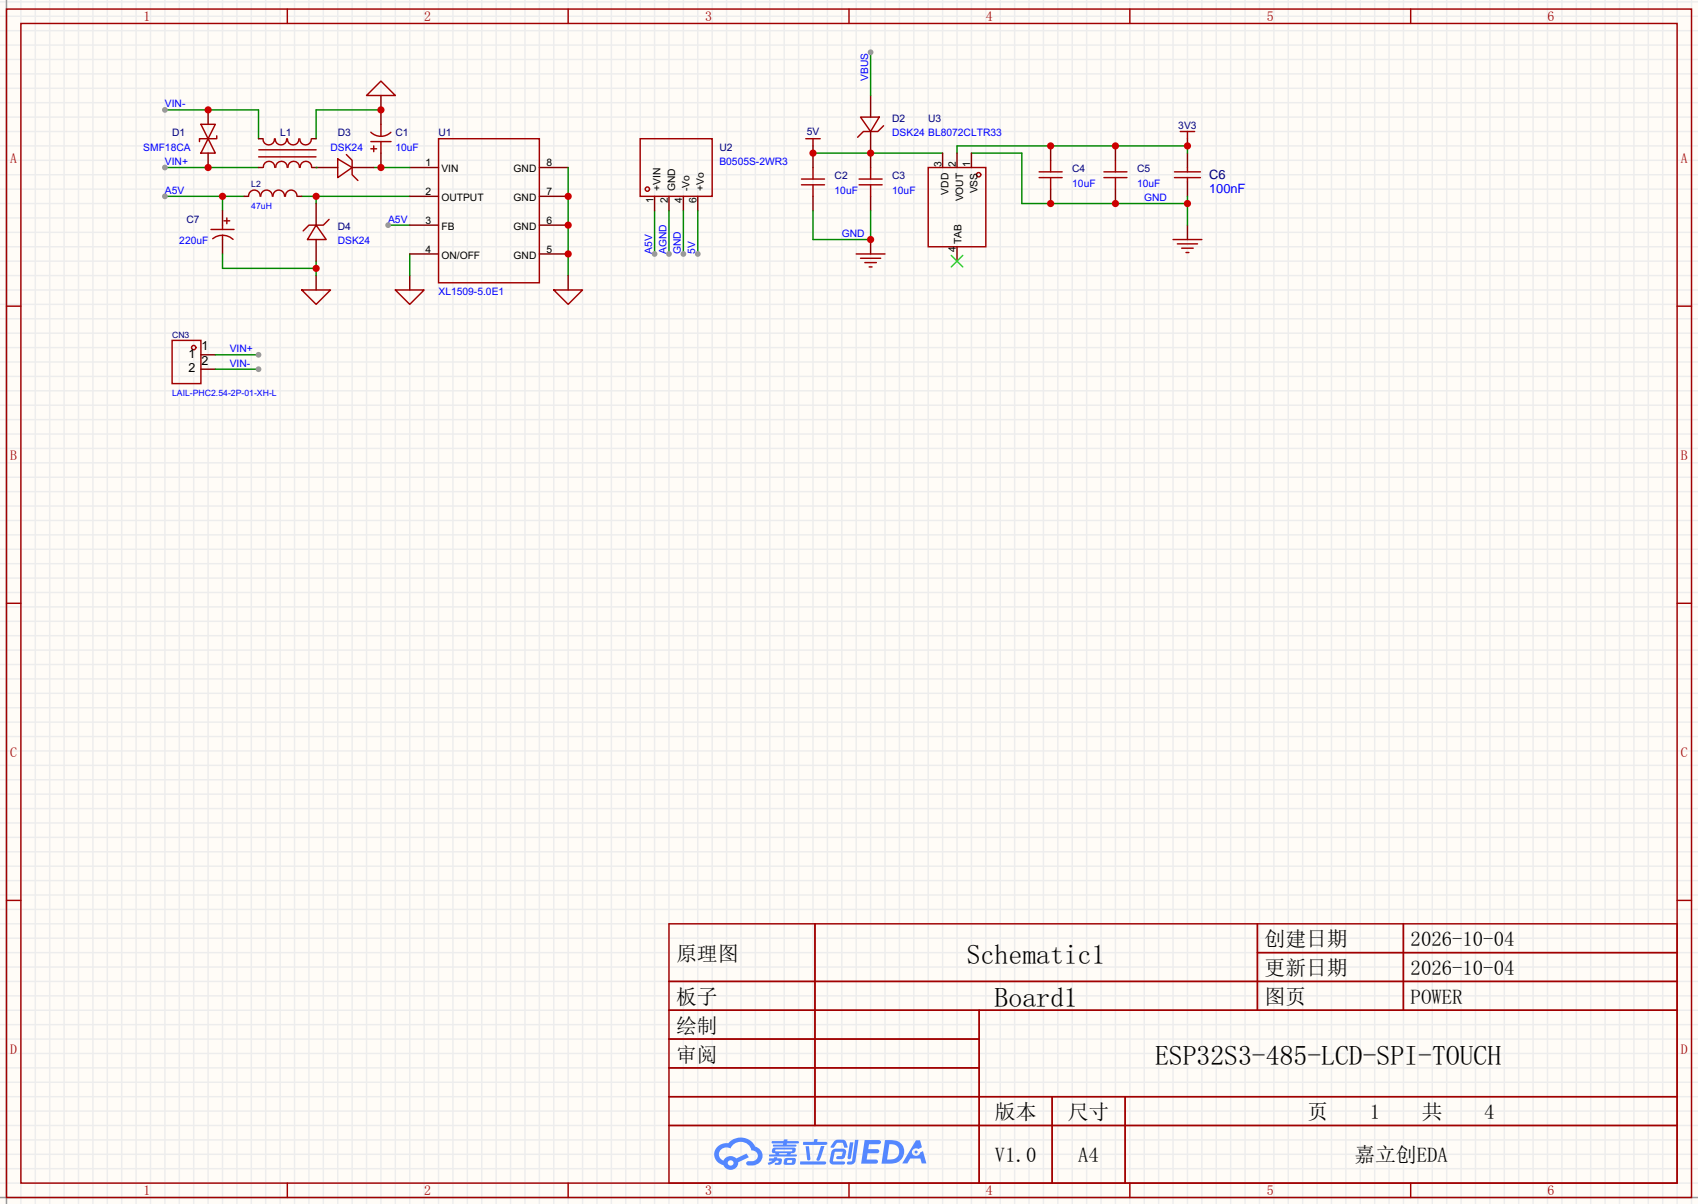
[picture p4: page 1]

D1 | | | D3 | C1 | U1 | | | | | 5V | | DSK24 | | BL8072CLTR33 | | | | 3V3 L1

SMF18CA | DSK24 | 10uF | U2

VIN 1 | GND | 8 | | | C2 | | | | C4 | C5 | | | C6

47uH | | | | OUTPUT 2 | GND | 7 | | | | | | | | | GND

D4 | | FB 3 | | GND | | 6 | | GND

220uF | | DSK24

ON/OFF 4 | | GND | | 5

CN3
1 | VIN+
1 | 2 | VIN-

更新日期 | 2026-10-04

板子 | Board1 | | 图页 | POWER
绘制

D | 审阅 | | ESP32S3-485-LCD-SPI-TOUCH | | | D

A | USB_N | | | DP2 B6 | | | | | | | | | | | | ESP_EN | | EN 3 | | IO2 | 38 | LCD-SPI-MISO | | 100nF | | | 3V3 | | | A
GND | GND

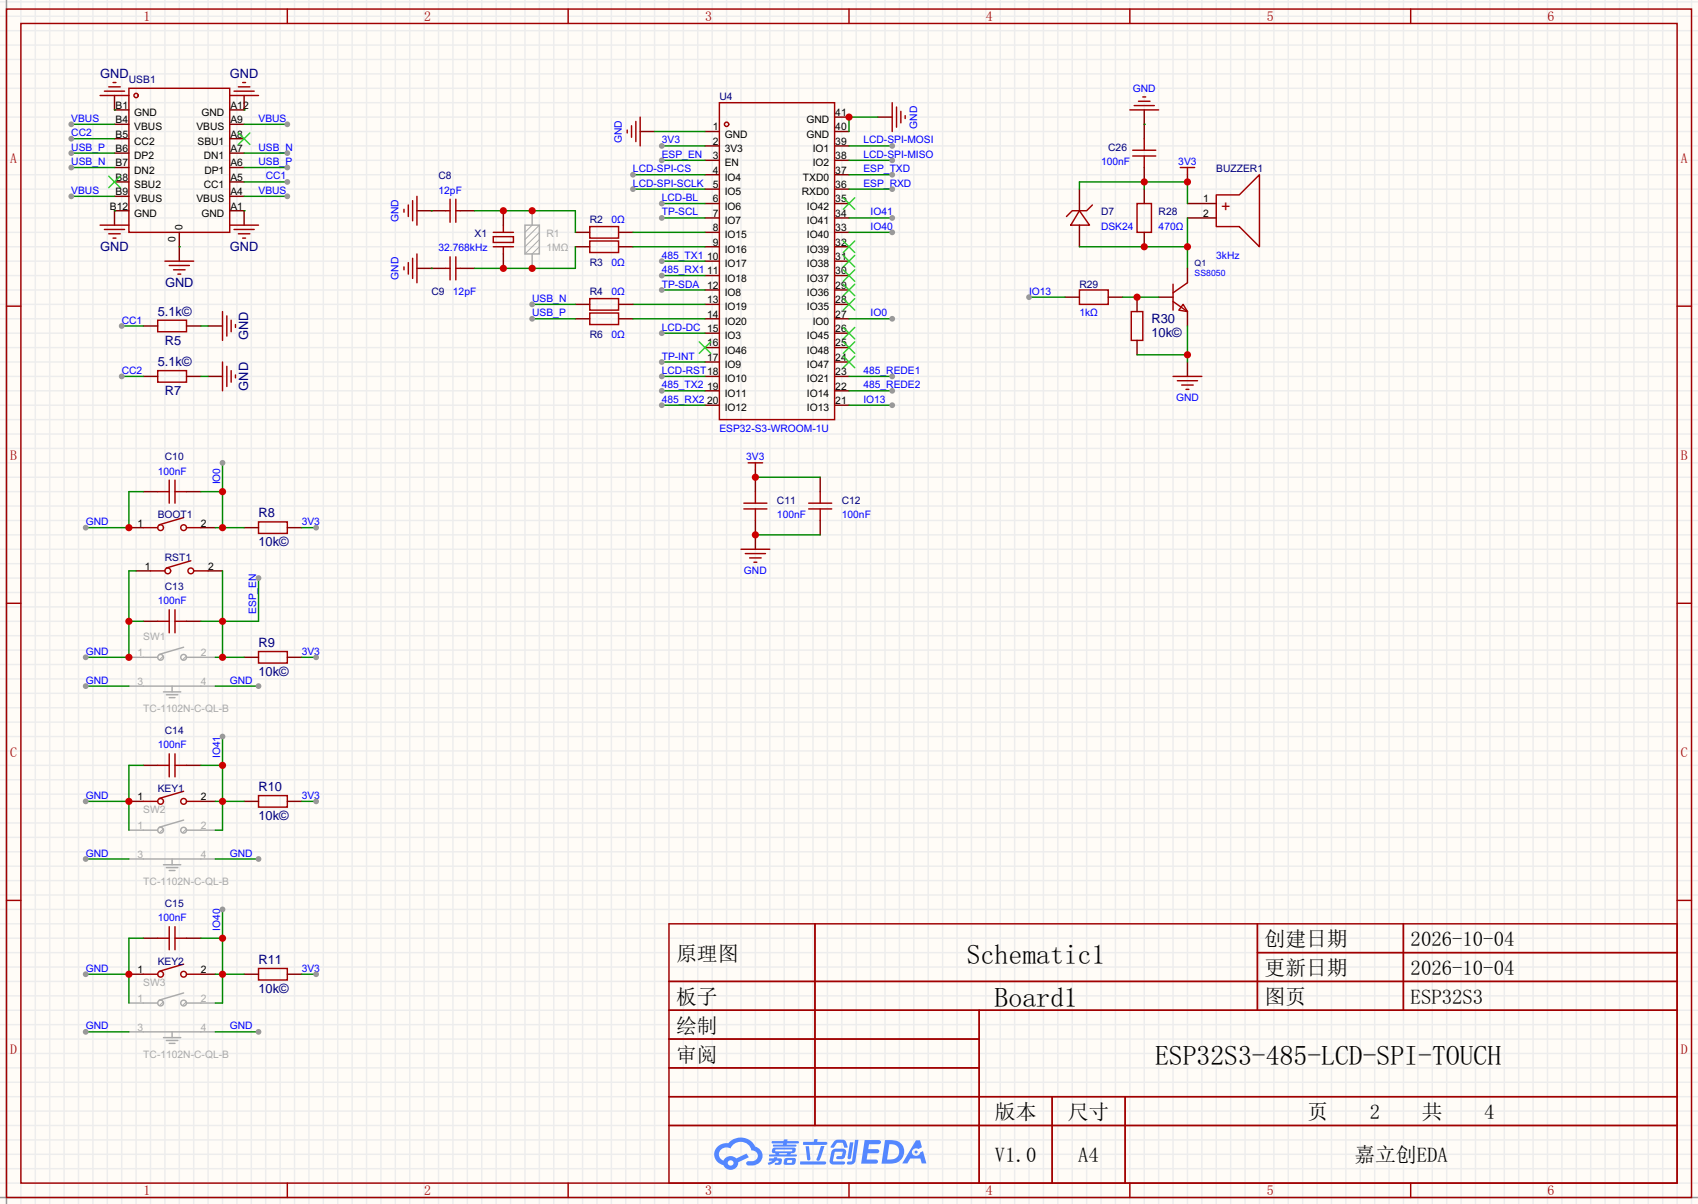
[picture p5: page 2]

USB1 | | | | | | | | | | | | | | | | | | | | | | GND

VBUS | | | GND B1 | | | VBUS
CC2 | | | VBUS B4 | | | | | | | | | | | | | | GND 1

USB_P | | | CC2 B5 | GND A1 VBUS A4 CC1 A5 DP1 A6 DN1 A7 SBU1 A8 VBUS A9 GND A12 | | USB_N | | | | | | | | | 3V3 | | 3V3 2 | | IO1 | 39 | LCD-SPI-MOSI | | C26

DN2 B7 | | | | | C8 | | | | | | LCD-SPI-CS | | | IO4 4 | TXD0 | | 37 | ESP_TXD | | | | | | | BUZZER1

USB_P
CC1

VBUS | | | SBU2 B8 | | | | | 12pF | | | | | | LCD-SPI-SCLK | | | IO5 5 | RXD0 | | 36 | ESP_RXD
VBUS

VBUS B9 | | | | | | | | | | | | LCD-BL | | IO6 6 | IO42 | | 35 | | | | | | | 1
GND B12 | | | | | | | | | R2 | 0Ω | | TP-SCL | | IO7 7 | IO41 | | 34 | | IO41 | D7 | | R28 | | 2 | +

X1 | R1 | | | | | | | IO15 8 | IO40 | | 33 | | IO40 | DSK24 | | 470Ω

GND | | | | GND | | | 32.768kHz | | | 1MΩ | | | | | | | IO39 | | 32

USB_N | | | | | | IO11 19 IO10 18 IO9 17 IO46 16 IO3 15 IO20 14 IO19 13 IO8 12 IO18 11 IO17 10 IO16 9 | | | IO13 IO35 | | 21 IO12 20 28

R3 | 0Ω | | 485_TX1 | | | | IO38 | 31 | | | | | | | | Q1 | | 3kHz

GND | C9 | 12pF | | | R4 | | 0Ω | TP-SDA | | | | IO36 | | 29 | | | IO13 | R29

CC1 | 5.1k© | | | | USB_P | | | | | | | | | | IO0 | 27 | | IO0 | | 1kΩ | R30

R6 | | 0Ω | LCD-DC | | | | IO45 | | 26 | | | | | | 10k©

R5 | | | | | | | | | | | | IO48 | | 25
5.1k© | | | | | | | | | TP-INT | | | | IO47 | | 24

CC2 | | | | | | | | | | LCD-RST | | | | IO21 | | 23 | 485_REDE1

R7 | | | | | | | | 485_TX2 | | | | IO14 | | 22 | 485_REDE2

485_RX2 | | | | | | | IO13 | | | | | | | GND

GND | SW1 | GND IO⁴⁰ | ESP_EN IO⁴¹ IO⁰

GND | | BOOT1 | | | | R8 | | 3V3 | | 100nF | | 100nF

RST1
1 | | | 2 | | | | GND
C13
100nF

GND | | | | | | | R9 | | 3V3

GND | | KEY1 | | | | R10 | 3V3

GND | | | | | GND

C15

原理图 | Schematic1 | 创建日期 | 2026-10-04

GND | | KEY2 | | | | R11 | 3V3 | | | | 更新日期 | 2026-10-04

10k© | | 板子 | | Board1 | 图页 | ESP32S3

GND | | | | | GND | | | | 绘制

D | TC-1102N-C-QL-B | | 审阅 | ESP32S3-485-LCD-SPI-TOUCH | D

| 100© | | | DE 5 | B | 13 | R17 | 120Ω | | 3 | 3 | 485B1 | 3V3 | VDDA 1 | VDDB | | 8 | | 1
| | | 3 | R | NC | 11 | 22© | | ZX-XH2.54-4PZZ | | | | ESP_TXD | VI2 3 | | VO2 | 6 | BTXD | | 3 | 2 3

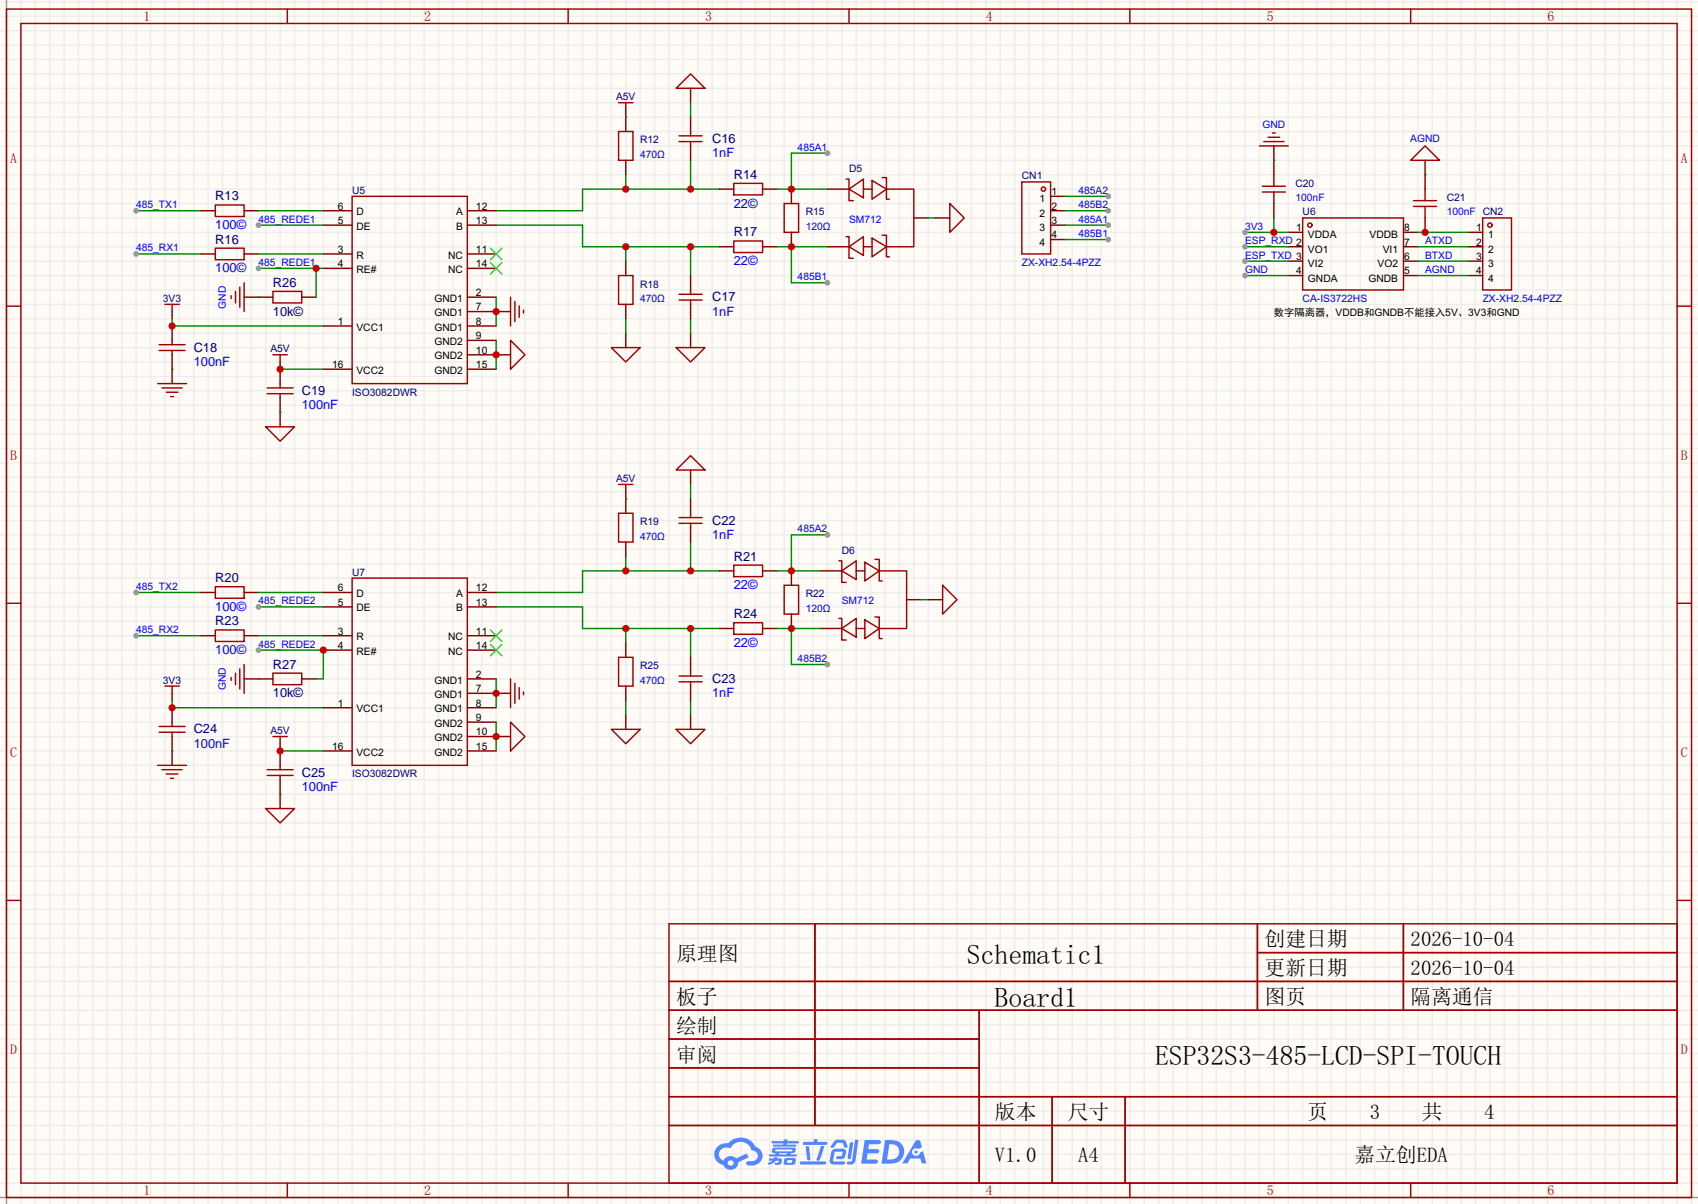
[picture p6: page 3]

GND

R12 | C16 | | 485A1 | | | | | | | | | AGND

485_REDE1

485_RX1 | R16 | | | | | | | | | 4 | 4 | | ESP_RXD | VO1 2 | | VI1 | 7 | ATXD | | 2 | 1

100© | | | RE# 4 | | NC | 14 | | | | 485B1 | GND | GNDA 4 | | | GNDB | 5 | AGND | 4

3V3 | | | | | | | GND1 | | 2 | 470Ω | C17 | | | | | CA-IS3722HS | | | | | ZX-XH2.54-4PZZ

10k© | | | | GND1 | | 7 | | 1nF | | | | 数字隔离器，VDDB和GNDB不能接入5V、3V3和GND

VCC1 1 | GND1 | | 8

C18 | | A5V | | | | GND2 | | 9
100nF | | | | | | GND2 | | 10

GND2 | | 15 VCC2 16
C19 | | ISO3082DWR

R19 | C22
470Ω | 1nF | 485A2

100© | 485_REDE2 | | | DE 5 | | B | 13 | | | | | 120Ω | SM712
R23 | | | | | | | | | | R24

100© | 485_REDE2 | | | RE# 4 | | NC | 14 | | | 22©

3V3 | | | | | | GND1 | | 2 | 470Ω | C23

10k© | GND1 | | 7 | | 1nF

GND2 | | 9

C24 | A5V | | | GND2 | | 10

C | 100nF | | | | GND2 | | 15 VCC2 16 | | C

C25 | ISO3082DWR
100nF

更新日期 | 2026-10-04

板子 | Board1 | | 图页 | 隔离通信
绘制

D | 审阅 | | ESP32S3-485-LCD-SPI-TOUCH | | | D

A | 5 | 5 | | A

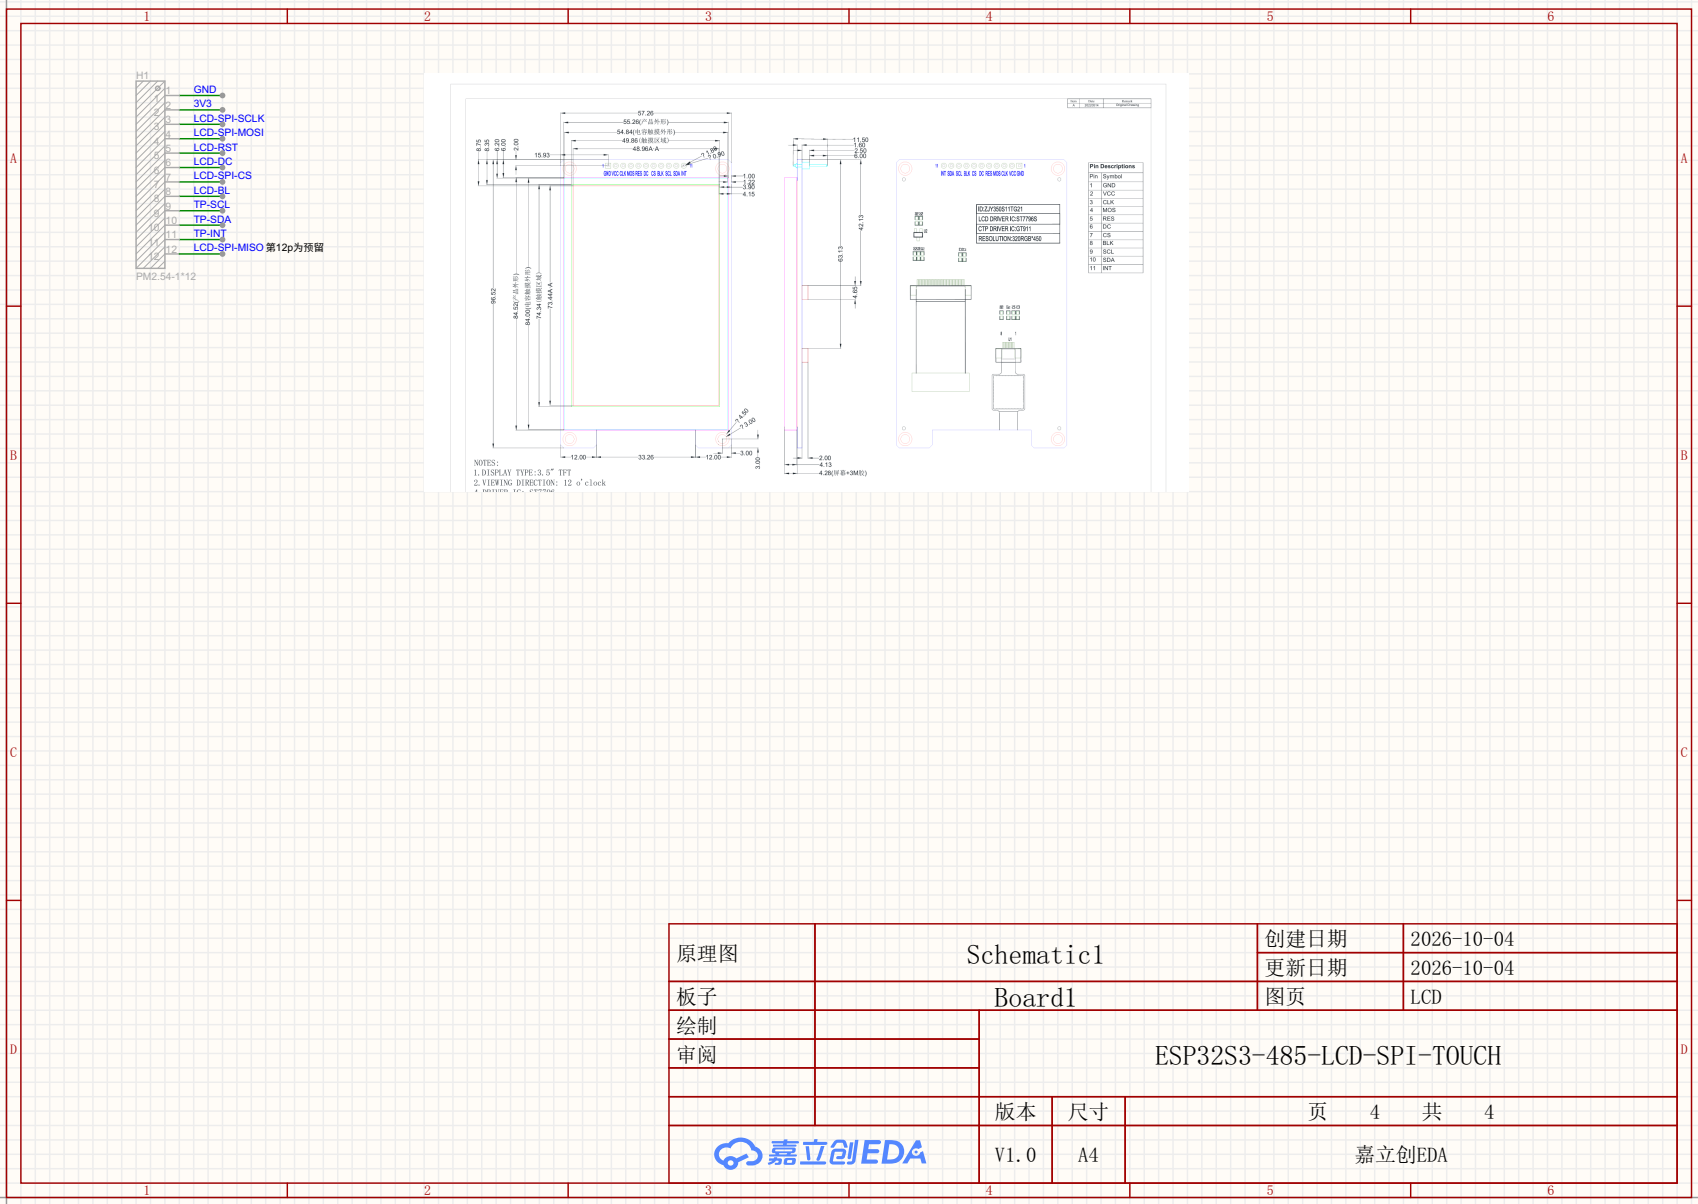
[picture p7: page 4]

GND
3V3
3 | | LCD-SPI-MOSI

2 | 2 | LCD-SPI-SCLK

LCD-RST
LCD-DC
LCD-SPI-CS
8 | LCD-BL
10 | 10
11 | 11 | LCD-SPI-MISO 第12p为预留
12 | 12

TP-SCL
TP-SDA
TP-INT

更新日期 | 2026-10-04

板子 | Board1 | | 图页 | LCD
绘制

D | 审阅 | | ESP32S3-485-LCD-SPI-TOUCH | | | D

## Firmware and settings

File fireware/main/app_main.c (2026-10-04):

#include <inttypes.h>
#include "board_pins.h"
#include "board_lvgl.h"
#include "buttons.h"
#include "buzzer.h"
#include "charger_service.h"
#include "nvs_flash.h"
#include "lcd_st7796.h"
#include "touch_gt911.h"
#include "serial_port.h"
#include "modbus_rtu.h"
#include "esp_log.h"
#include "esp_psram.h"
#include "esp_system.h"
#include "esp_timer.h"
#include "freertos/task.h"
#include "sdkconfig.h"

static const char *TAG = "app";
static bool report(const char *name, esp_err_t err)
{
    if (err != ESP_OK) { ESP_LOGE(TAG, "%s: %s", name, esp_err_to_name(err)); return false; }
    ESP_LOGI(TAG, "%s ready", name);
    return true;
}
static void serial_task(void *arg)
{
    (void)arg;
    uint8_t data[128];
    for (;;) {
        int n = serial_port_read(data, sizeof(data), pdMS_TO_TICKS(100));
        if (n > 0) {
            ESP_LOGI(TAG, "isolated UART RX: %d bytes", n);
            ESP_LOG_BUFFER_HEX_LEVEL(TAG, data, n, ESP_LOG_INFO);
#ifdef CONFIG_BOARD_SERIAL_ECHO
            report("UART echo", serial_port_write(data, n));
#endif
        } else if (n < 0) {
            ESP_LOGE(TAG, "UART read failed"); vTaskDelay(pdMS_TO_TICKS(100));
        }
    }
}
#ifdef CONFIG_BOARD_MODBUS_DEMO
typedef struct {
    rs485_port_t port;
    uint8_t slave;
    uint16_t start_register;
} modbus_demo_config_t;
static const modbus_demo_config_t modbus_demo_configs[RS485_PORT_COUNT] = {
    {RS485_PORT_1, CONFIG_BOARD_MODBUS1_SLAVE, CONFIG_BOARD_MODBUS1_START_REGISTER},
    {RS485_PORT_2, CONFIG_BOARD_MODBUS2_SLAVE, CONFIG_BOARD_MODBUS2_START_REGISTER},
};
static void modbus_task(void *arg)
{
    const modbus_demo_config_t *cfg = arg;
    for (;;) {
        uint16_t registers[2];
        uint8_t exception = 0;
        esp_err_t err = modbus_read_registers(cfg->port, cfg->slave, 3,
            cfg->start_register, 2, registers, 2000, &exception);
        if (err == ESP_OK) ESP_LOGI(TAG, "RS485-%d Modbus registers: %u, %u", cfg->port + 1, registers[0], registers[1]);
        else ESP_LOGW(TAG, "RS485-%d Modbus: %s (0x%x), exception=0x%02x", cfg->port + 1, esp_err_to_name(err), err, exception);
        vTaskDelay(pdMS_TO_TICKS(2000));
    }
}
#endif
static unsigned init_modbus_ports(void)
{
    unsigned ready_mask = 0;
    uart_parity_t parity[RS485_PORT_COUNT] = {UART_PARITY_DISABLE, UART_PARITY_DISABLE};
    uart_stop_bits_t stop[RS485_PORT_COUNT] = {UART_STOP_BITS_1, UART_STOP_BITS_1};
#ifdef CONFIG_BOARD_RS4851_PARITY_EVEN
    parity[0] = UART_PARITY_EVEN;
#elif defined(CONFIG_BOARD_RS4851_PARITY_ODD)
    parity[0] = UART_PARITY_ODD;
#endif
#ifdef CONFIG_BOARD_RS4852_PARITY_EVEN
    parity[1] = UART_PARITY_EVEN;
#elif defined(CONFIG_BOARD_RS4852_PARITY_ODD)
    parity[1] = UART_PARITY_ODD;
#endif
#ifdef CONFIG_BOARD_RS4851_TWO_STOP_BITS
    stop[0] = UART_STOP_BITS_2;
#endif
#ifdef CONFIG_BOARD_RS4852_TWO_STOP_BITS
    stop[1] = UART_STOP_BITS_2;
#endif
    const int baud[RS485_PORT_COUNT] = {CONFIG_BOARD_RS4851_BAUD, CONFIG_BOARD_RS4852_BAUD};
    const char *names[RS485_PORT_COUNT] = {"RS485-1 UART1 TX17/RX18/DE21", "RS485-2 UART2 TX11/RX12/DE14"};
    for (unsigned i = 0; i < RS485_PORT_COUNT; ++i) {
        bool ok = report(names[i], rs485_init((rs485_port_t)i, baud[i], parity[i], stop[i]));
        if (ok) ready_mask |= 1U << i;
#ifdef CONFIG_BOARD_MODBUS_DEMO
        if (ok && xTaskCreate(modbus_task, i == 0 ? "modbus1" : "modbus2", 4096,
                              (void *)&modbus_demo_configs[i], 3, NULL) != pdPASS)
            ESP_LOGE(TAG, "Cannot create Modbus task for port %u", i + 1);
#else
        if (ok) ESP_LOGI(TAG, "RS485-%u transport ready", i + 1);
#endif
    }
    return ready_mask;
}
void app_main(void)
{
    report("GPIO13 buzzer OFF", buzzer_init());
#ifdef CONFIG_BOARD_CHARGER_APP
    /* Keep existing credentials/settings on NVS errors; never silently erase. */
    bool storage_ok = report("NVS", nvs_flash_init());
#endif
    ESP_LOGI(TAG, "ESP32-S3-WROOM-1U-N16R8 basic drivers, IDF %s", esp_get_idf_version());
    ESP_LOGI(TAG, "PSRAM detected: %u bytes", (unsigned)esp_psram_get_size());
    bool lcd_ok = report("ST7796 480x320 landscape", lcd_init());
    if (lcd_ok) {
#ifdef CONFIG_BOARD_LCD_COLOR_TEST
        report("LCD red", lcd_fill_rect(0, 0, BOARD_LCD_WIDTH / 3, BOARD_LCD_HEIGHT, 0xF800));
        report("LCD green", lcd_fill_rect(BOARD_LCD_WIDTH / 3, 0, BOARD_LCD_WIDTH / 3, BOARD_LCD_HEIGHT, 0x07E0));
        report("LCD blue", lcd_fill_rect(2 * BOARD_LCD_WIDTH / 3, 0, BOARD_LCD_WIDTH / 3, BOARD_LCD_HEIGHT, 0x001F));
#else
        report("LCD clear", lcd_fill(0x0000));
#endif
        report("LCD backlight", lcd_set_backlight(80));
    }
    bool touch_ok = report("GT911", touch_init());
    report("GPIO41 reserved (200 ms filter), GPIO40 touch toggle (2 s hold)", buttons_init());
    ESP_LOGI(TAG, "Touch input enabled at boot; hold GPIO40 for 2 seconds to toggle");
    if (report("CN2 isolated UART0", serial_port_init(CONFIG_BOARD_SERIAL_BAUD, UART_PARITY_DISABLE, UART_STOP_BITS_1))) {
        if (xTaskCreate(serial_task, "serial_demo", 4096, NULL, 3, NULL) != pdPASS)
            ESP_LOGE(TAG, "Cannot create serial task");
    }
    unsigned ports_ready = init_modbus_ports();
#ifdef CONFIG_BOARD_CHARGER_APP
    if (storage_ok && report("Dual charger service", charger_service_init(ports_ready))) {
        if (report("Wi-Fi AP + STA", charger_network_start())) report("Charger web", charger_web_start());
    }
#else
    (void)ports_ready;
#endif
    bool gui_active = false;
#ifdef CONFIG_BOARD_LVGL_BENCHMARK
    if (lcd_ok) gui_active = report("LVGL benchmark", board_lvgl_start(touch_ok));
#endif
    uint8_t previous_count = 0;
    int64_t last_touch_log = 0, last_touch_error = 0, last_health = 0;
    const char *event_names[] = {"pressed", "released", "long press"};
    bool reserved_pressed = false;
    for (;;) {
        button_event_t event;
        while (buttons_get_event(&event, 0)) {
            ESP_LOGI(TAG, "KEY%d %s", event.id + 1, event_names[event.type]);
            if (event.id == BUTTON_KEY2 && event.type == BUTTON_LONG_PRESS && touch_ok) {
                bool enabled = !touch_is_enabled();
                esp_err_t err = touch_set_enabled(enabled);
                if (err == ESP_OK) ESP_LOGI(TAG, "Touch input %s by GPIO40", enabled ? "enabled" : "disabled");
                else ESP_LOGW(TAG, "Touch toggle failed: %s", esp_err_to_name(err));
            }
        }
        bool key1 = buttons_is_pressed(BUTTON_KEY1);
        if (key1 != reserved_pressed) {
            ESP_LOGI(TAG, "GPIO41 reserved state=%s (200 ms filtered)", key1 ? "pressed" : "released");
            reserved_pressed = key1;
        }
        int64_t now = esp_timer_get_time() / 1000;
        if (touch_ok && !gui_active) {
            touch_frame_t frame;
            esp_err_t err = touch_read(&frame);
            if (err != ESP_OK) {
                if (now - last_touch_error >= 1000) {
                    ESP_LOGW(TAG, "Touch read: %s", esp_err_to_name(err)); last_touch_error = now;
                }
            } else if (frame.updated) {
                if (frame.count != previous_count || (frame.count && now - last_touch_log >= 100)) {
                    if (!frame.count) ESP_LOGI(TAG, "Touch released");
                    for (unsigned i = 0; i < frame.count; ++i)
                        ESP_LOGI(TAG, "Touch id=%u x=%u y=%u size=%u", frame.points[i].id,
                            frame.points[i].x, frame.points[i].y, frame.points[i].size);
                    last_touch_log = now;
                }
                previous_count = frame.count;
            }
        }
        if (now - last_health >= 30000) {
            ESP_LOGI(TAG, "free heap=%" PRIu32 ", minimum=%" PRIu32,
                     esp_get_free_heap_size(), esp_get_minimum_free_heap_size());
            last_health = now;
        }
        vTaskDelay(pdMS_TO_TICKS(10));
    }
}

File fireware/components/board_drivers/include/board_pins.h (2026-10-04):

#pragma once

/* SCH_Schematic1_2026-10-04.pdf, pages 2-4. GPIO numbers, not module pin numbers. */
#define BOARD_LCD_MOSI       1
#define BOARD_LCD_MISO       2  /* H1 pin 12 is reserved; not connected to LCD SDO. */
#define BOARD_LCD_DC         3
#define BOARD_LCD_CS         4
#define BOARD_LCD_SCLK       5
#define BOARD_LCD_BL         6
#define BOARD_TOUCH_SCL      7
#define BOARD_TOUCH_SDA      8
#define BOARD_TOUCH_INT      9
#define BOARD_DISPLAY_RST   10  /* LCD RESET and GT911 CTP_RST share RES. */
#define BOARD_RS4851_TX     17
#define BOARD_RS4851_RX     18
#define BOARD_RS4851_DE_RE  21  /* U5, CN1 pins 3/4; high = TX. */
#define BOARD_RS4852_TX     11
#define BOARD_RS4852_RX     12
#define BOARD_RS4852_DE_RE  14  /* U7, CN1 pins 1/2; high = TX. */
#define BOARD_BUZZER        13  /* Active buzzer via Q1: high = sound. */
#define BOARD_KEY1          41  /* Reserved input, 200 ms stable filter. */
#define BOARD_KEY2          40  /* Hold 2 s to toggle touch input. */
#define BOARD_SERIAL_TX     43
#define BOARD_SERIAL_RX     44
#define BOARD_LCD_NATIVE_WIDTH   320
#define BOARD_LCD_NATIVE_HEIGHT  480
#define BOARD_LCD_WIDTH          480
#define BOARD_LCD_HEIGHT         320
#define BOARD_TOUCH_ADDR  0x5D  /* Seven-bit address (datasheet 0xBA/0xBB). */
